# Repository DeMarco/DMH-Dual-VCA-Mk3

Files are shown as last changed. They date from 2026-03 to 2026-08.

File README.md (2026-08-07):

# DMH-Dual-VCA-Mk3
Version 3 of my stereo VCA in Kosmo format, now including voltage controlled panning and optional clipping and distortion!







## Features

- 2 channels, A and B
- 2 CV inputs per channel, each one with its own attenuverter knob
- Unipolar control voltage: 0V means VCA is fully closed (gain = 0), +10V means completely open (gain = 1)
- 1 offset knob per channel, useful to bias bipolar CV signals like those from LFOs
- The offset setting and attenuverted CV inputs of each channel are summed
- Toggle switches to select between pan/balanced/tremolo mode, and clipping/distortion
- Pan mode: output volue of both channels is halved. Pan CV signal will increase one channel's volume and decrease the other's simultaneously.
- Balanced mode: same as Pan mode, but both channels volume are biased with half the Pan CV signal amplitude, which preserves overall volume during panning.
- Tremolo mode: both channels duck in response to Pan CV.
- The Pan knob can be used to manually change panning when no Pan CV is plugged in. It becomes an attenuverter when Pan CV is used.
- Clip mode: 4v7 Zener diode pairs are applied to both channel outputs, effectively limiting output to about +/-5V.
- Distorted mode: 3v0 Zener diode pairs and 2x gain is applied to both channels output, effectively distorting and limiting output to +/-5V.
- LEDs indicate when the output levels pre-clipping/distortion peak above 5V, so you know that Clip mode is clipping the output when engaged.

Demo video: https://www.instagram.com/reel/DbrHDk0sg0o/?utm_source=ig_web_copy_link&igsh=MzRlODBiNWFlZA==

## Schematic and Gerbers

https://github.com/DeMarco/DMH-Dual-VCA-Mk3/blob/main/Schematic.pdf

https://github.com/DeMarco/DMH-Dual-VCA-Mk3/tree/main/Gerbers

https://github.com/DeMarco/DMH-Dual-VCA-Mk3/blob/main/DMH_Output_BoM.csv

Please note the plug-in VCA submodules are part of another Repo. You need to make 4 of these to assemble the complete module:

https://github.com/DeMarco/DMH-Submodules/tree/main/DMH_Submodule_VCA/Gerbers

## Assembly instructions

Use 11mm long pin headers on the Main PCB to ensure connection with the pin sockets on the Controls PCB.
Other than that, nothing special.
I recommend soldering components in order of height: start with resistors and diodes, then move on to IC sockets, capacitors, transistors and connectors.

### Main PCB




### Controls PCB




### VCA Submodule Mk1




## Calibration

### Attenuverters pot center

t.b.w.

### VCAs symmetry

t.b.w

## Current consumption

+12V --> 38mA

-12V --> 38mA

## Dimensions

Height: 20cm

Width: 5cm

Depth: t.b.c.

## Font

For viewing/customizing in KiCad, I recommend downloading and installing the Nulshock font from Typodermic: https://typodermicfonts.com/nulshock/

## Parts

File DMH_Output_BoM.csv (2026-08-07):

Reference | Value | Footprint | Qty | DNP
C1,C2,C6,C7,C8,C9,C10,C11,C12,C13,C14,C15,C16,C17,C18,C19,C24,C25 | 100nF | Capacitor_THT:C_Disc_D4.3mm_W1.9mm_P5.00mm | 18
C3 | 22pF | Capacitor_THT:C_Disc_D3.0mm_W2.0mm_P2.50mm | 1
C4,C5 | 47uF | Capacitor_THT:CP_Radial_D5.0mm_P2.00mm | 2
C20,C21 | 2.2uF | Capacitor_THT:CP_Radial_D4.0mm_P1.50mm | 2
C22,C23 | 22uF | Capacitor_THT:CP_Radial_D4.0mm_P1.50mm | 2
D1,D2 | 1N4148 | Diode_THT:D_DO-35_SOD27_P7.62mm_Horizontal | 2
D3,D4 | SB140 | Diode_THT:D_DO-41_SOD81_P10.16mm_Horizontal | 2
D5,D6 | LED_R | LED_THT:LED_D3.0mm | 2
D7,D8,D9,D10 | ZPD4V7 | Diode_THT:D_DO-35_SOD27_P7.62mm_Horizontal | 4
D11,D12,D13,D14 | ZPD3V0 | Diode_THT:D_DO-35_SOD27_P7.62mm_Horizontal | 4
J1,J2,J3,J4,J5,J6,J7,J8,J9 | TRS_Jack_6.35mm_Sw | SynthStuff:CUI_SJ-63083D | 9
J11,J13 | Conn_01x06 | Connector_PinHeader_2.54mm:PinHeader_1x06_P2.54mm_Vertical | 2
J12,J21 | Conn_01x08 | Connector_PinHeader_2.54mm:PinHeader_1x08_P2.54mm_Vertical | 2
J14,J16 | Conn_01x06 | Connector_PinSocket_2.54mm:PinSocket_1x06_P2.54mm_Vertical | 2
J15,J24 | Conn_01x08 | Connector_PinSocket_2.54mm:PinSocket_1x08_P2.54mm_Vertical | 2
J18,J19,J22,J23 | Conn_02x03_Odd_Even | Connector_PinSocket_2.54mm:PinSocket_2x03_P2.54mm_Vertical | 4
J25,J26,J27,J28 | Conn_02x03_Odd_Even | Connector_PinHeader_2.54mm:PinHeader_2x03_P2.54mm_Horizontal | 4
J100 | IDC_02x05 | SynthStuff:IDC-Header_2x05_P2.54mm_Vertical_Eurorack | 1
J200 | IDC_02x05 | SynthStuff:IDC-Header_2x05_P2.54mm_Vertical_BackBone | 1
JP1,JP2,JP3,JP4 | Jumper | Connector_PinHeader_2.54mm:PinHeader_1x03_P2.54mm_Vertical | 4
Q1,Q2,Q3,Q4,Q5,Q6,Q7,Q8,Q9,Q10,Q11,Q12 | BC548 | Package_TO_SOT_THT:TO-92L_Inline_Wide | 12
R1,R2 | 3k3 | Resistor_THT:R_Axial_DIN0207_L6.3mm_D2.5mm_P7.62mm_Horizontal | 2
R3,R64,R65,R70,R71 | 33k | Resistor_THT:R_Axial_DIN0207_L6.3mm_D2.5mm_P7.62mm_Horizontal | 5
R4,R5,R6,R7,R8,R12,R13,R14,R15,R16,R17,R25,R26,R27,R28,R29,R37,R38,R39,R40,R41,R49,R50,R51,R52,R53,R61,R62,R63,R67,R68,R69,R73,R74,R75,R80,R81,R82,R83,R84,R87,R92,R93,R96,R97 | 100k | Resistor_THT:R_Axial_DIN0207_L6.3mm_D2.5mm_P7.62mm_Horizontal | 45
R9,R11,R19,R21,R31,R33,R43,R45,R55,R57 | 20k | Resistor_THT:R_Axial_DIN0207_L6.3mm_D2.5mm_P7.62mm_Horizontal | 10
R10,R20,R23,R24,R32,R35,R36,R44,R47,R48,R56,R59,R60,R76,R78 | 10k | Resistor_THT:R_Axial_DIN0207_L6.3mm_D2.5mm_P7.62mm_Horizontal | 15
R18,R22,R30,R34,R42,R46,R54,R58 | 100R | Resistor_THT:R_Axial_DIN0207_L6.3mm_D2.5mm_P7.62mm_Horizontal | 8
R66,R72 | 18k | Resistor_THT:R_Axial_DIN0207_L6.3mm_D2.5mm_P7.62mm_Horizontal | 2
R77,R79 | 1k5 | Resistor_THT:R_Axial_DIN0207_L6.3mm_D2.5mm_P7.62mm_Horizontal | 2
R85,R88 | 4k7 | Resistor_THT:R_Axial_DIN0207_L6.3mm_D2.5mm_P7.62mm_Horizontal | 2
R86,R89,R100,R101 | 1k | Resistor_THT:R_Axial_DIN0207_L6.3mm_D2.5mm_P7.62mm_Horizontal | 4
R90,R91,R98,R99 | 2k2 | Resistor_THT:R_Axial_DIN0207_L6.3mm_D2.5mm_P7.62mm_Horizontal | 4
R94,R95 | 220k | Resistor_THT:R_Axial_DIN0207_L6.3mm_D2.5mm_P7.62mm_Horizontal | 2
RV1 | 50k | Potentiometer_THT:Potentiometer_Bourns_3296W_Vertical | 1
RV2,RV3,RV4,RV5 | 100k | Potentiometer_THT:Potentiometer_Bourns_3296X_Horizontal | 4
RV6 | 50k | Potentiometer_THT:Potentiometer_Alps_RK09L_Double_Vertical | 1
RV7,RV8,RV12,RV13 | 100k | SynthStuff:Potentiometer_TT_P110KH1 | 4
RV9,RV10,RV14,RV15 | 50k | Potentiometer_THT:Potentiometer_Bourns_3296X_Horizontal | 4
RV11,RV16 | 100k | SynthStuff:Potentiometer_Alpha_RD901F-40-00D_Single_Vertical | 2
SW1 | SW_DPDT_3way | SynthStuff:Toggle_Switch_2_Poles_TE | 1
SW2 | SW_DPDT_OnOffOn_x2 | SynthStuff:Toggle_Switch_2_Poles_TE | 1
U1,U2 | LM4040LP-5 | Package_TO_SOT_THT:TO-92L_Inline_Wide | 2
U3,U9,U10 | TL074 | Package_DIP:DIP-14_W7.62mm_Socket | 3
U4,U5,U6,U7,U8 | TL072 | Package_DIP:DIP-8_W7.62mm_Socket | 5

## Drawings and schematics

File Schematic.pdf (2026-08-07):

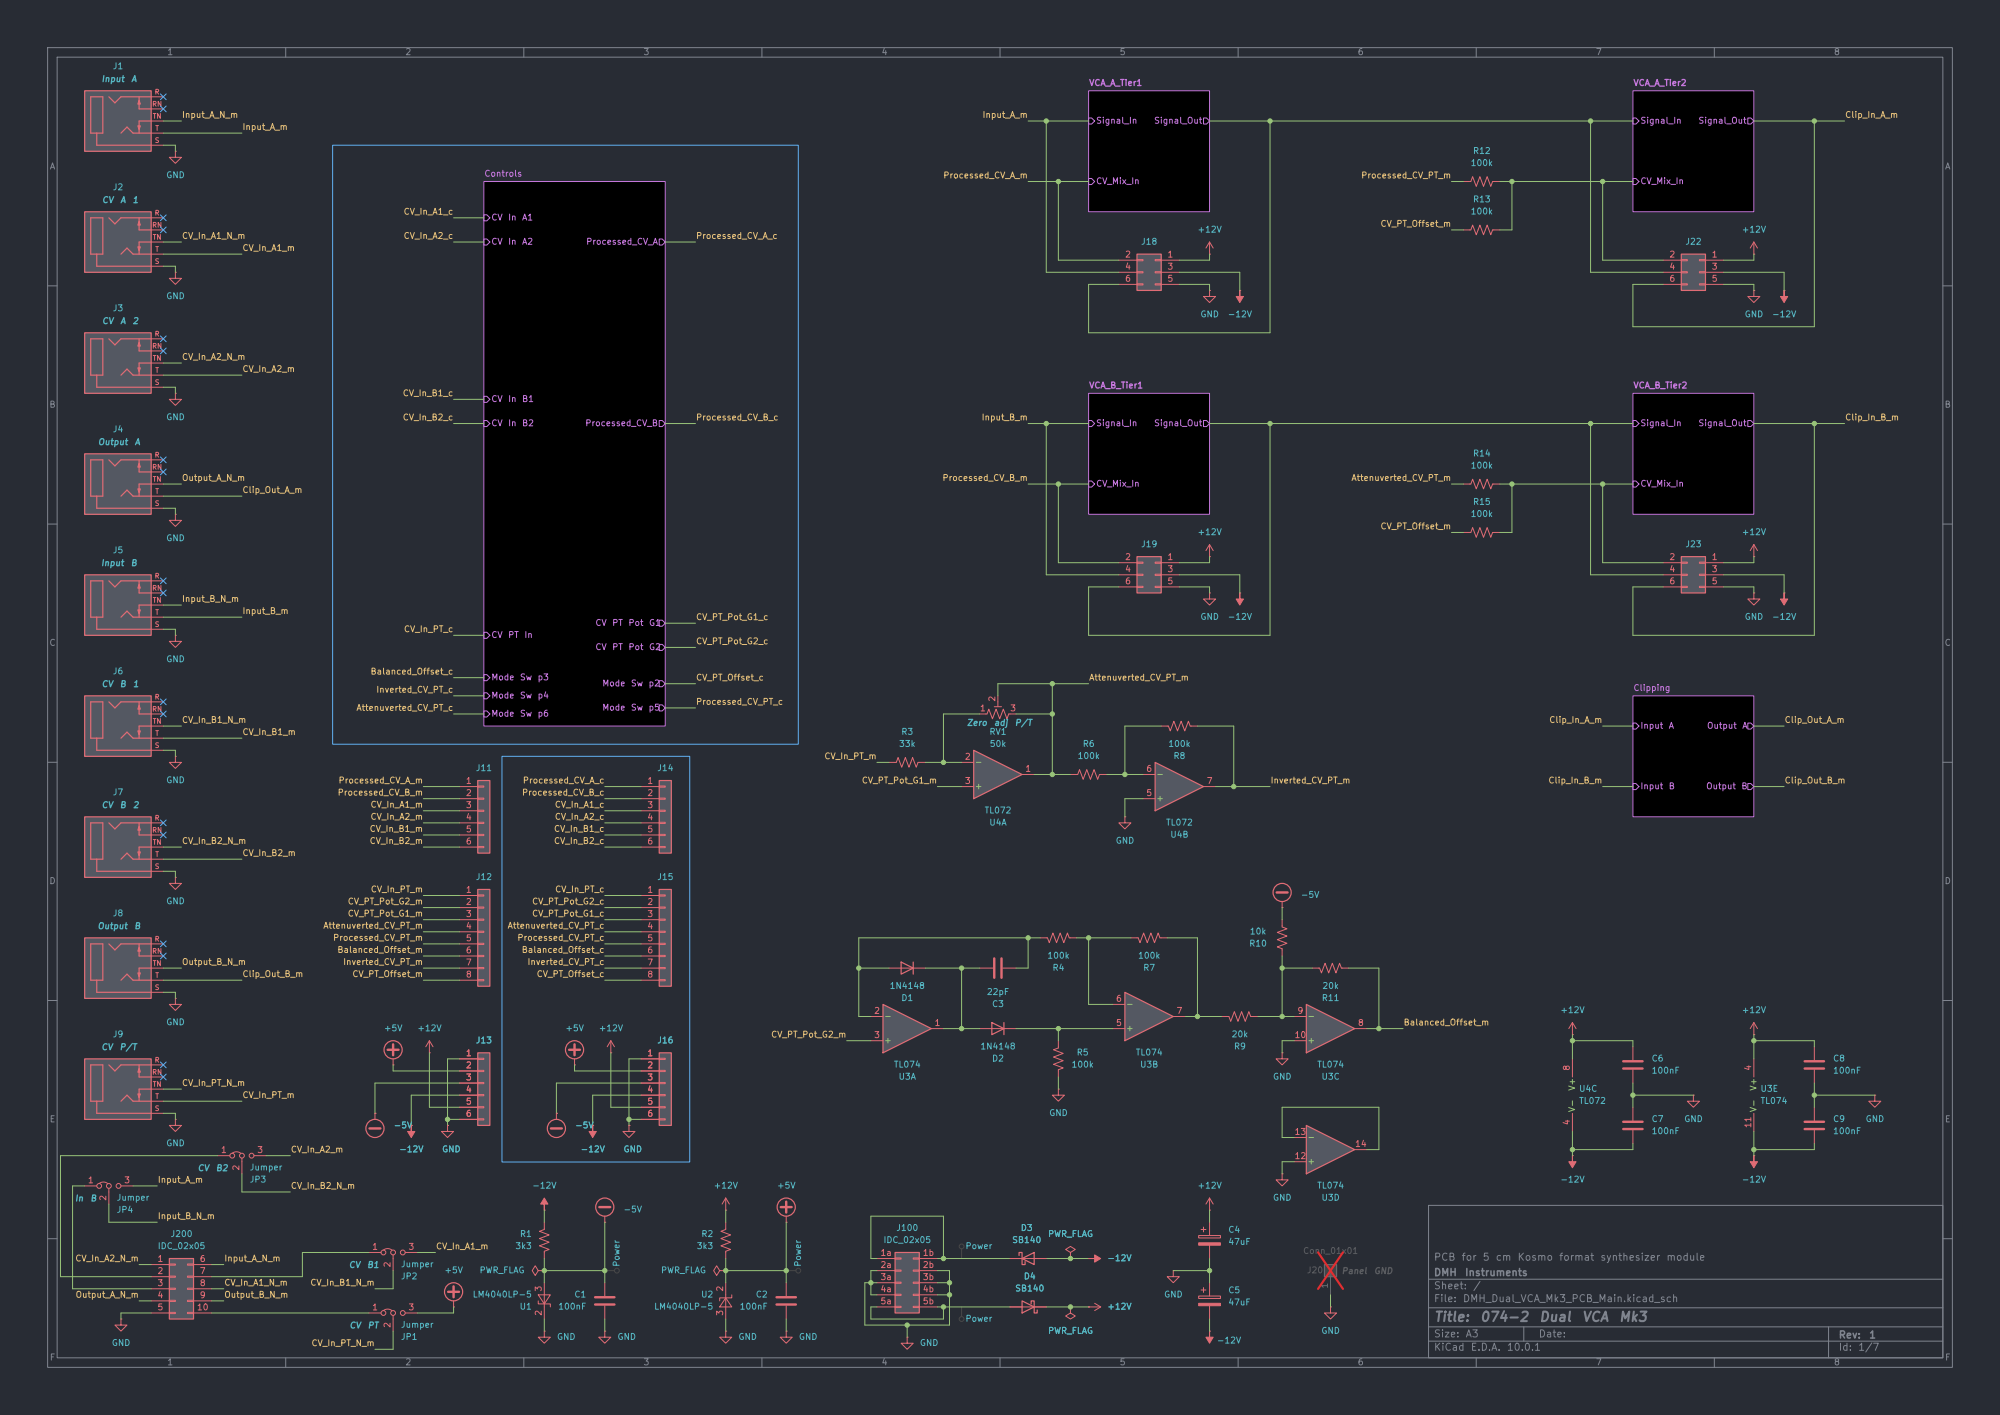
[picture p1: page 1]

PCB for 5 cm Kosmo format synthesizer module
DMH Instruments
Sheet: /
File: DMH_Dual_VCA_Mk3_PCB_Main.kicad_sch
Title: 074-2 Dual VCA Mk3

Size: A3 | Rev: 1 | F Date:
KiCad E.D.A. 10.0.1 | Id: 1/7

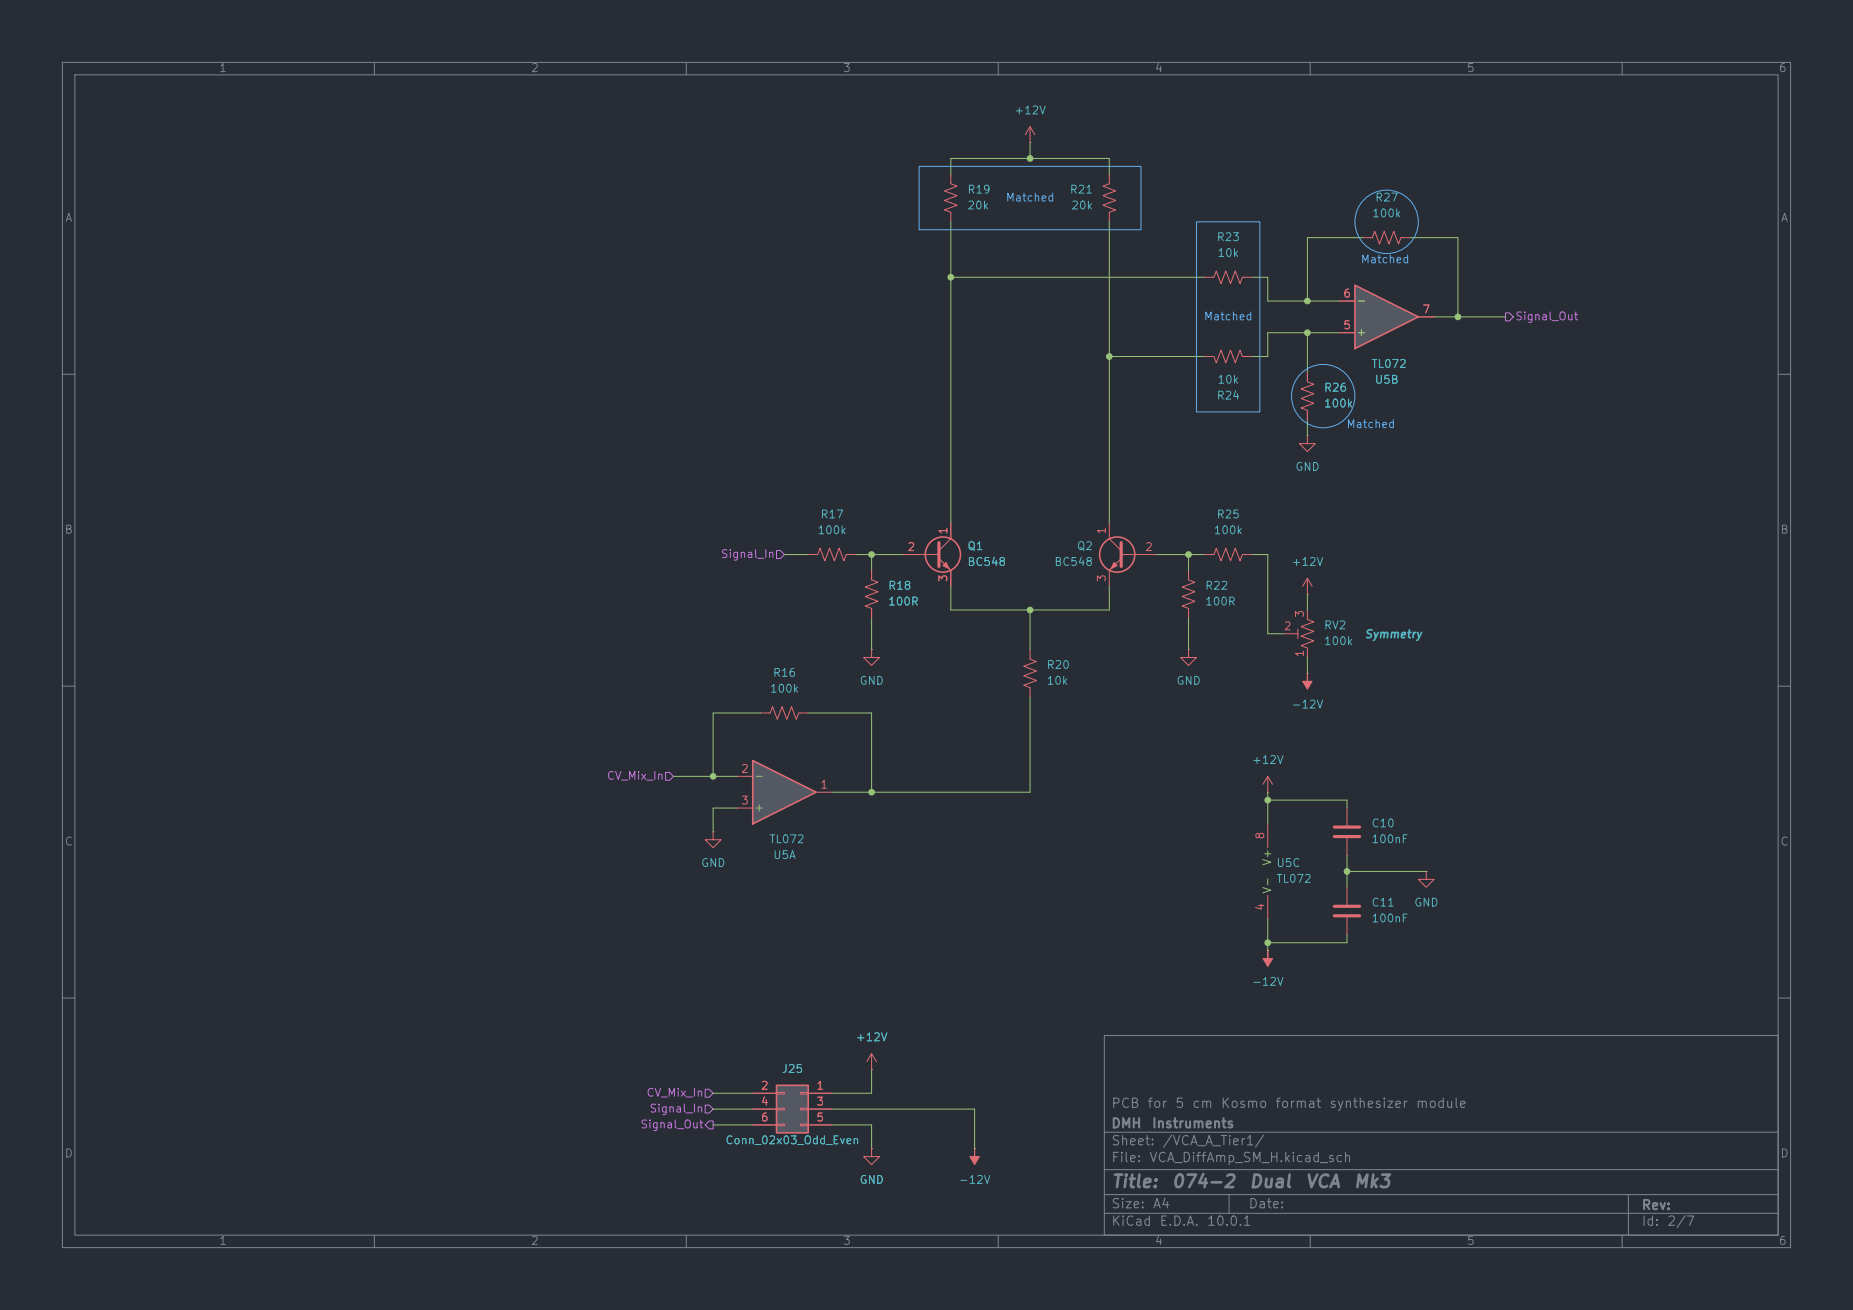
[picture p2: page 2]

PCB for 5 cm Kosmo format synthesizer module
DMH Instruments
Sheet: /VCA_A_Tier1/
File: VCA_DiffAmp_SM_H.kicad_sch
Title: 074-2 Dual VCA Mk3

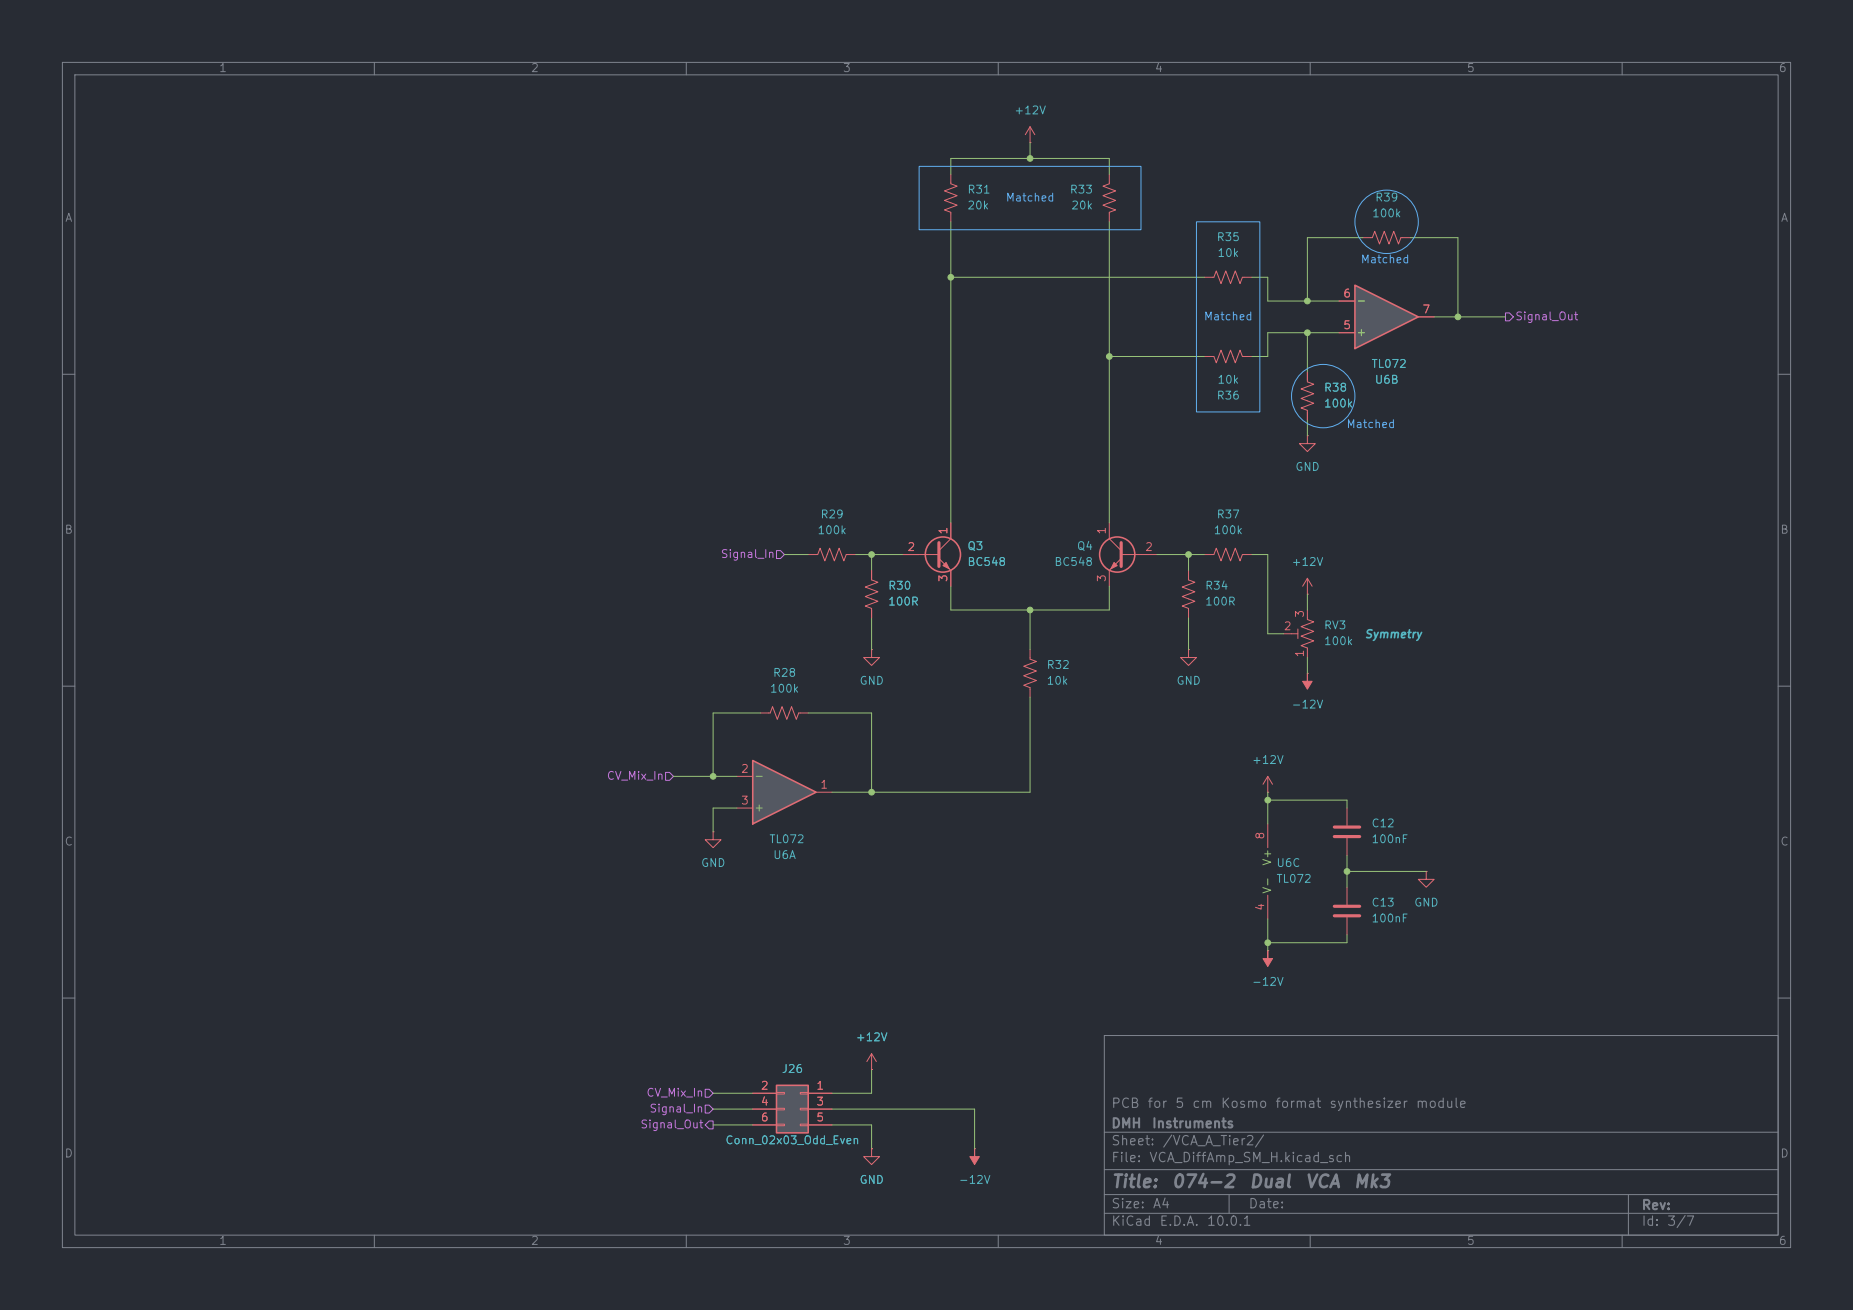
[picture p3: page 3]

PCB for 5 cm Kosmo format synthesizer module
DMH Instruments
Sheet: /VCA_A_Tier2/
File: VCA_DiffAmp_SM_H.kicad_sch
Title: 074-2 Dual VCA Mk3

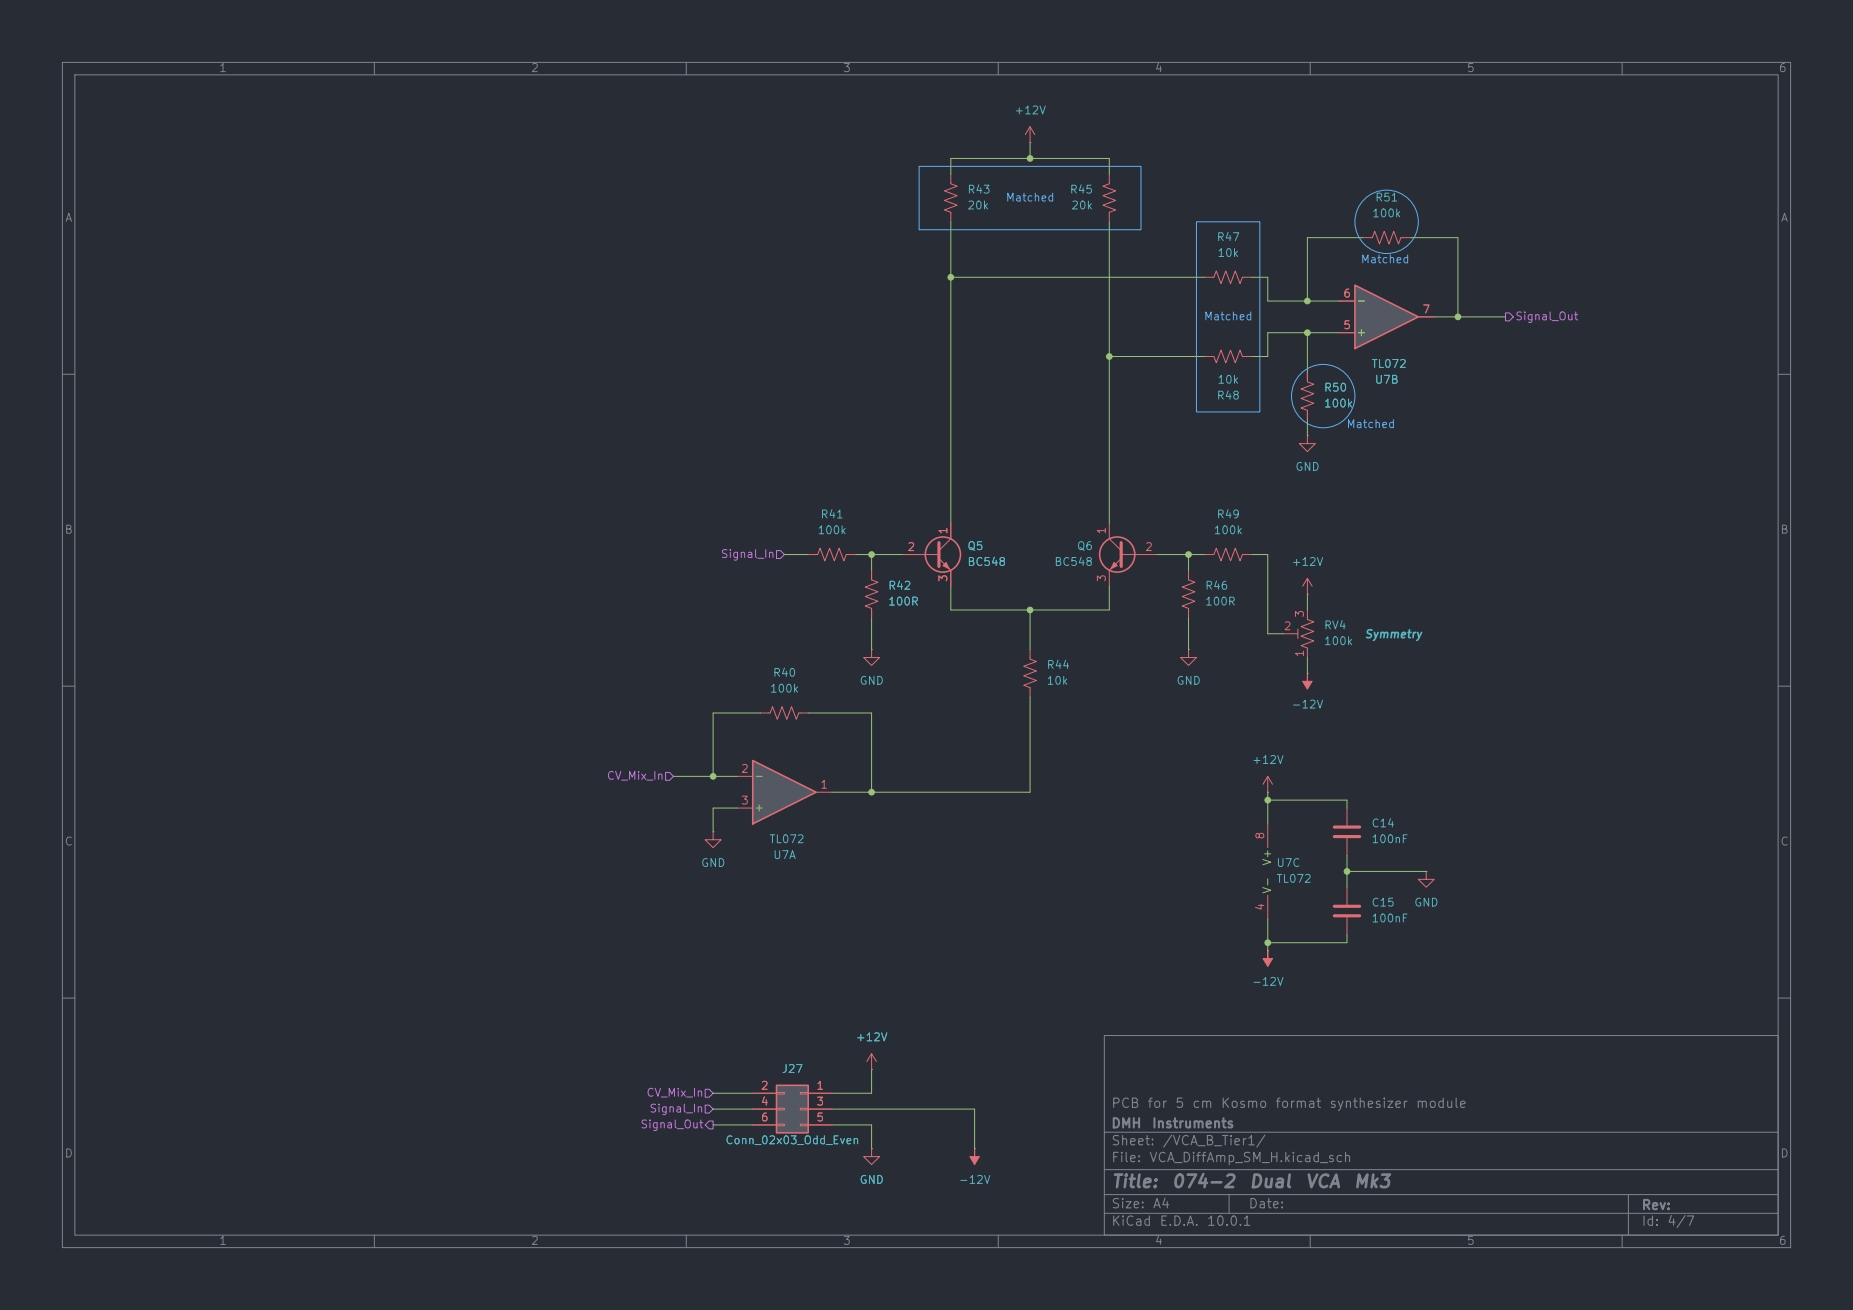
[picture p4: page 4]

PCB for 5 cm Kosmo format synthesizer module
DMH Instruments
Sheet: /VCA_B_Tier1/
File: VCA_DiffAmp_SM_H.kicad_sch
Title: 074-2 Dual VCA Mk3

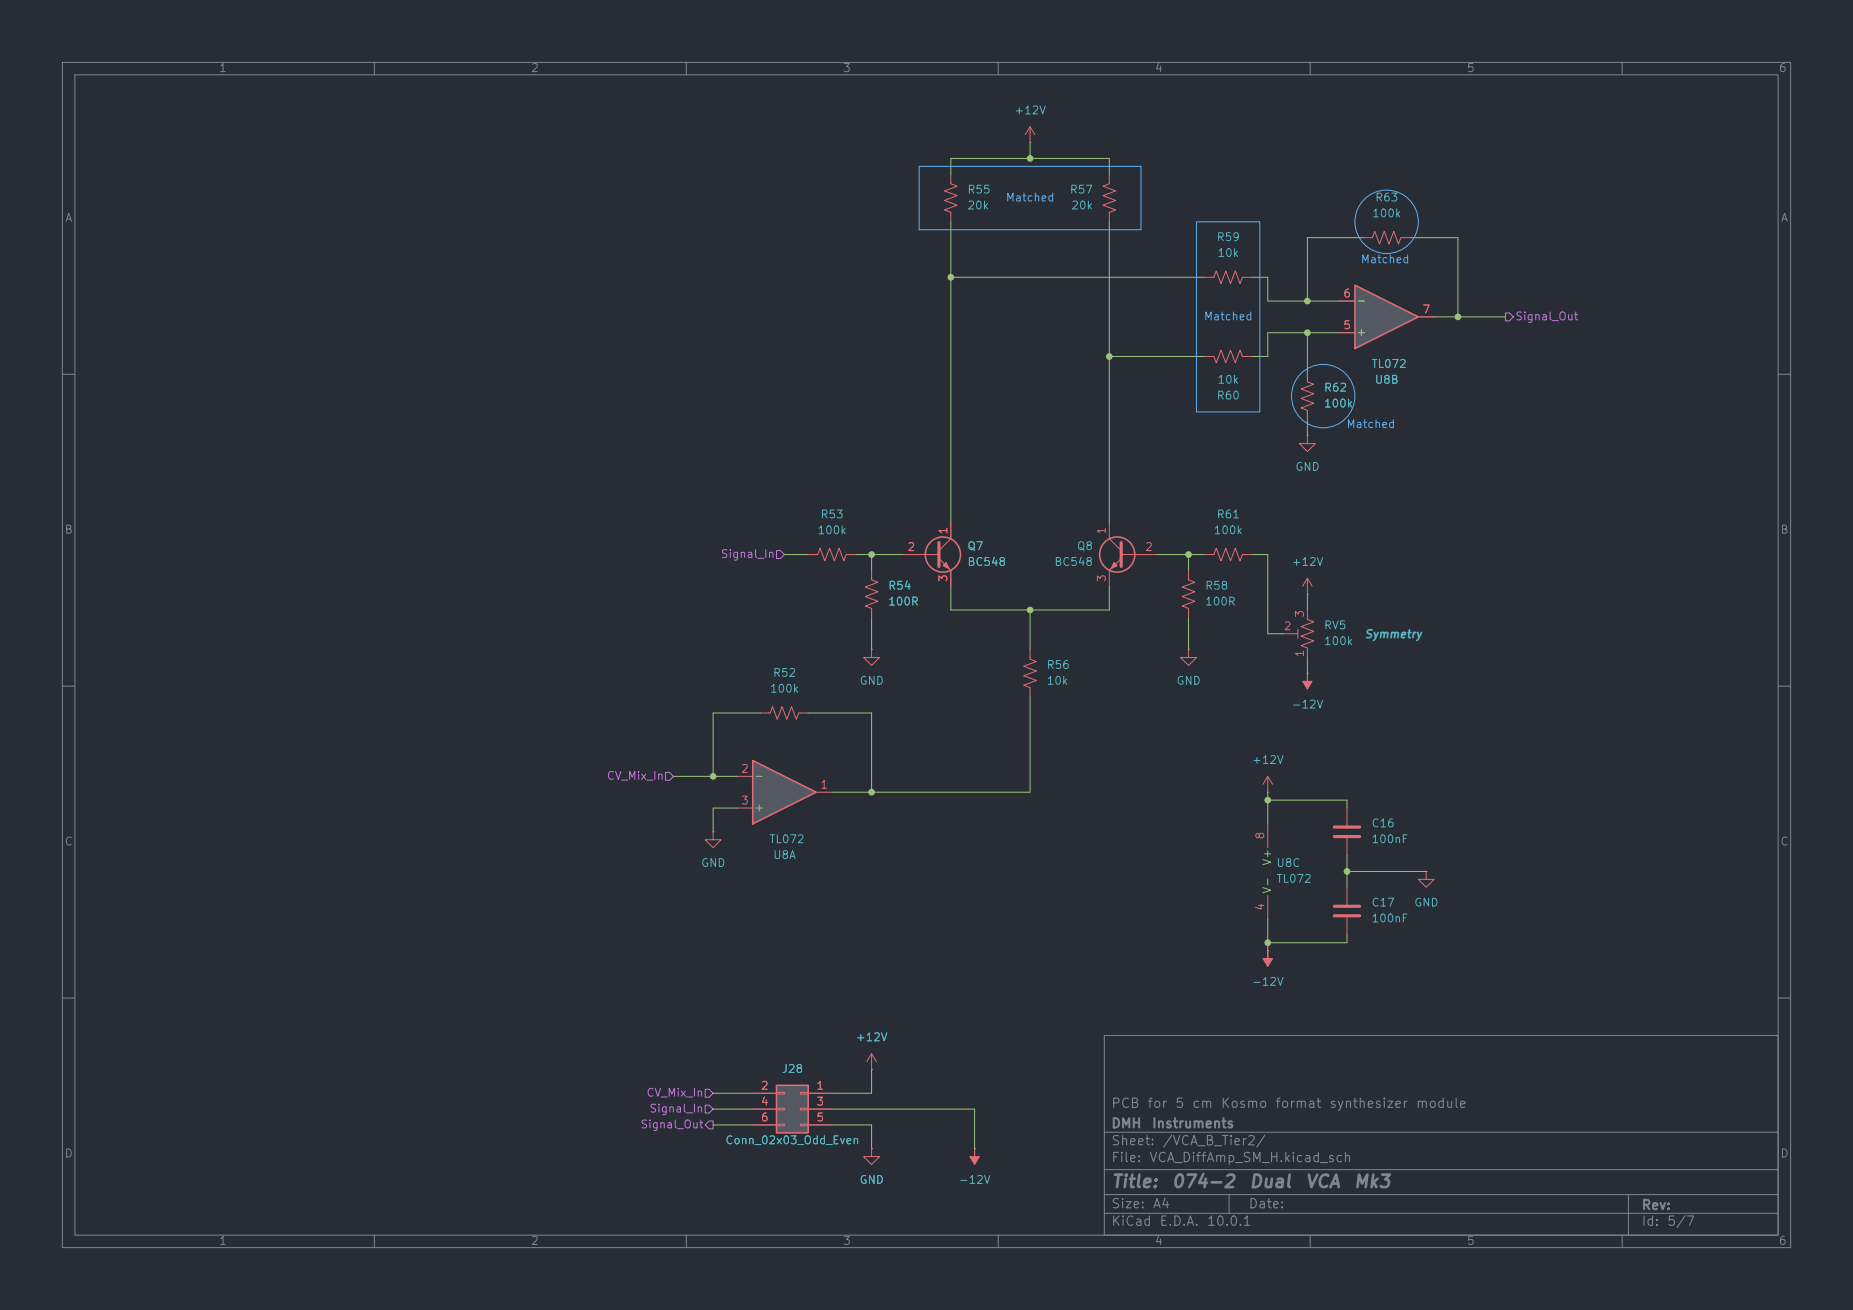
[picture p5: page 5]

PCB for 5 cm Kosmo format synthesizer module
DMH Instruments
Sheet: /VCA_B_Tier2/
File: VCA_DiffAmp_SM_H.kicad_sch
Title: 074-2 Dual VCA Mk3

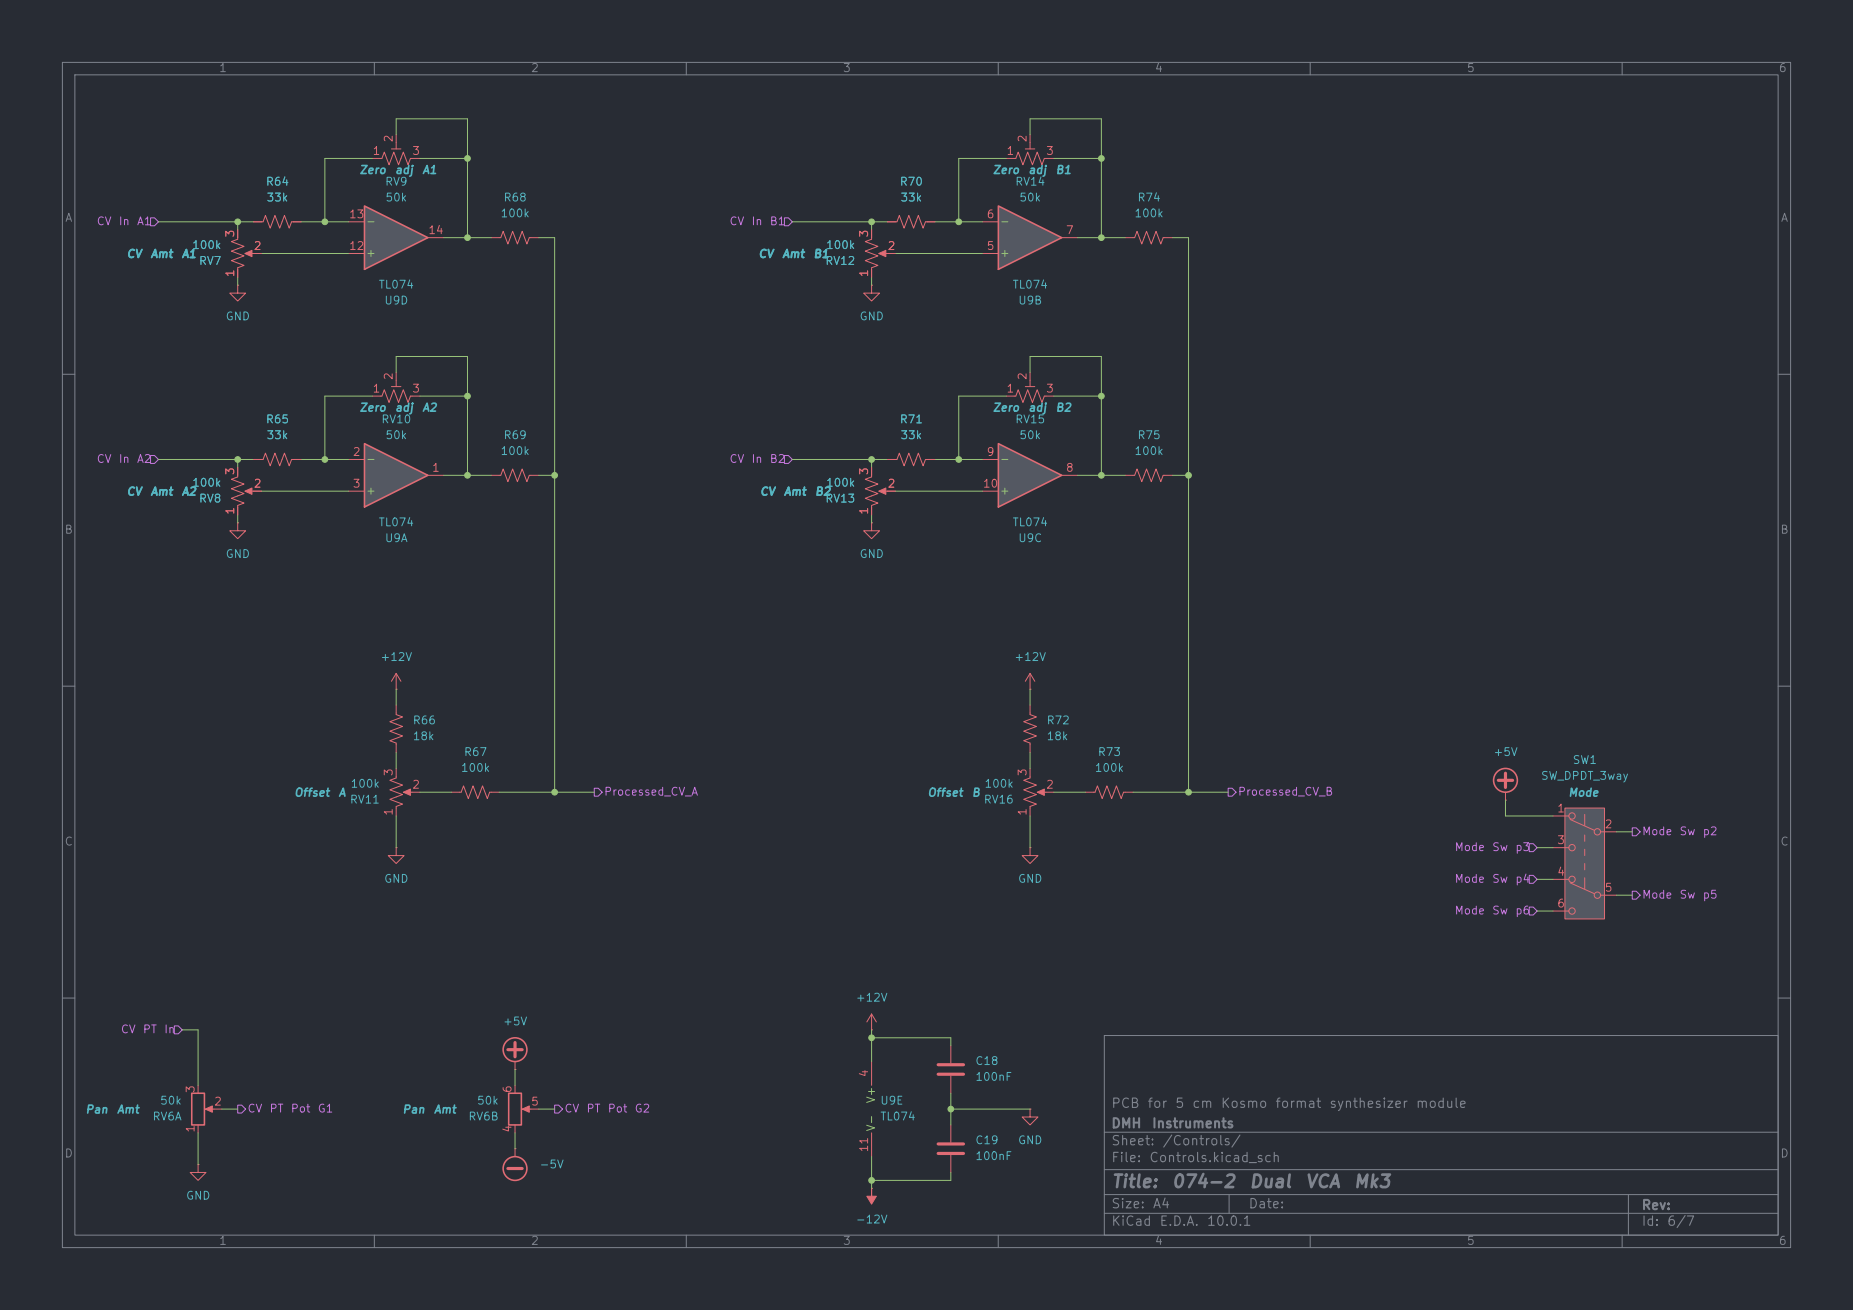
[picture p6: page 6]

PCB for 5 cm Kosmo format synthesizer module
DMH Instruments
Sheet: /Controls/
File: Controls.kicad_sch
Title: 074-2 Dual VCA Mk3

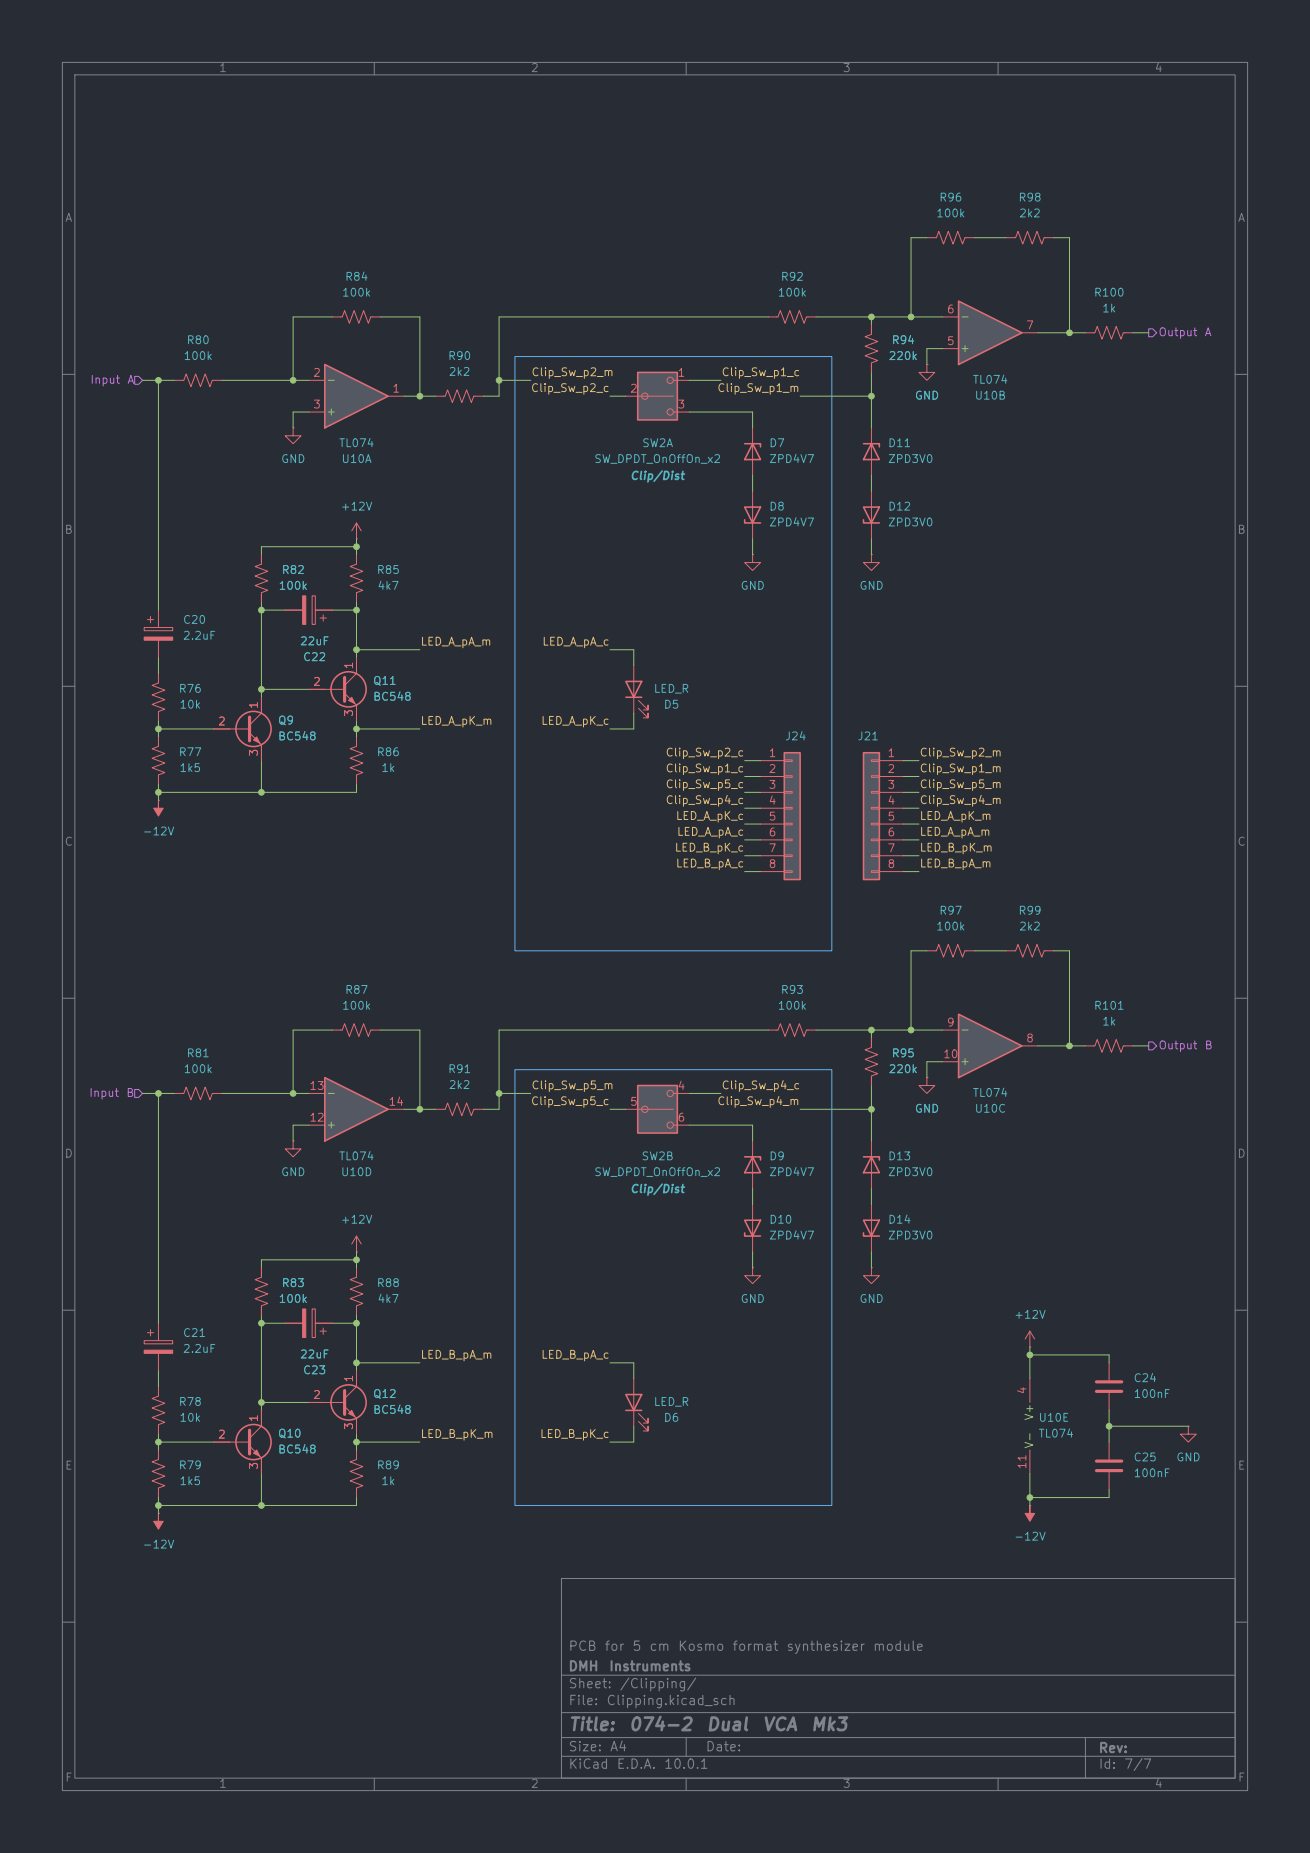
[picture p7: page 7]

PCB for 5 cm Kosmo format synthesizer module
DMH Instruments
Sheet: /Clipping/
File: Clipping.kicad_sch
Title: 074-2 Dual VCA Mk3

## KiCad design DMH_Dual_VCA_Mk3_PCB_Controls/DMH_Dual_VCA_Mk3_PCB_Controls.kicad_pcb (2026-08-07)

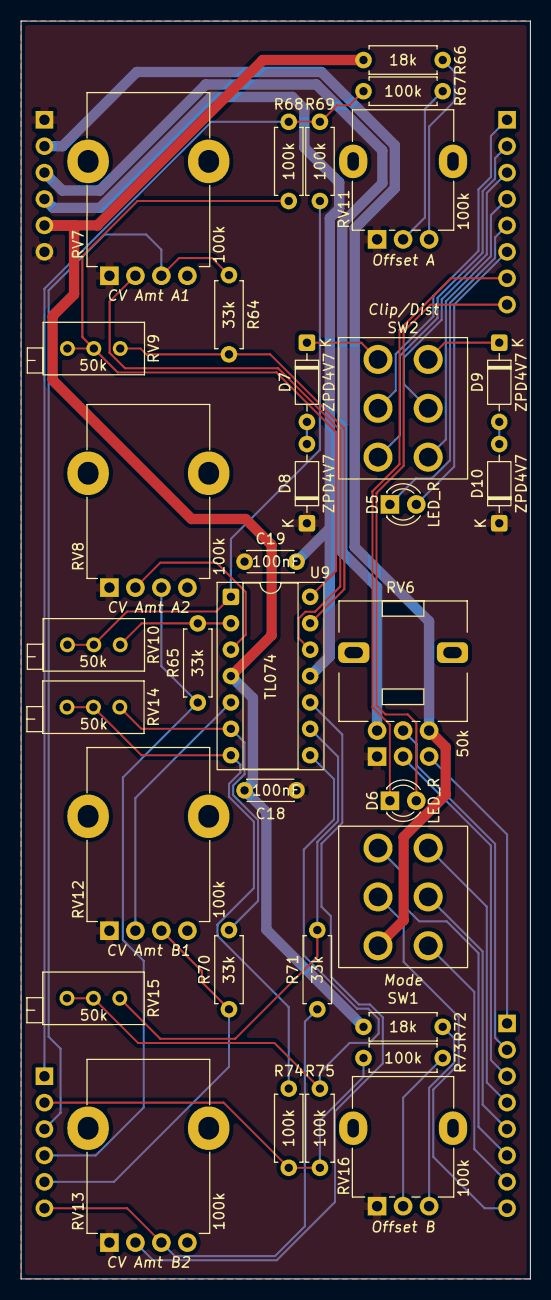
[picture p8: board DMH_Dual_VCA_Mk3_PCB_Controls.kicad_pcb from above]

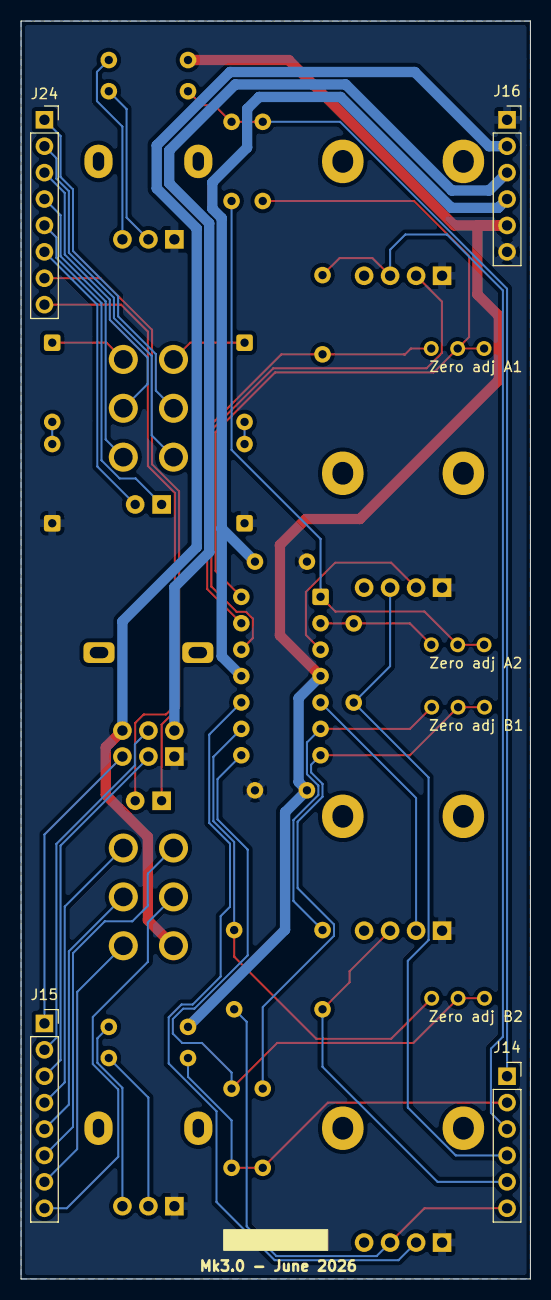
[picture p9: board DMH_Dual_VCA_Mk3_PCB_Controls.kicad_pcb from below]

Board: 2 copper layers, 49.0 x 121.0 mm, 38 parts (4 on the bottom side), 47 nets.

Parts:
C18, C19: 100nF; C_Disc_D4.3mm_W1.9mm_P5.00mm
D5, D6: LED_R; LED_D3.0mm
D7, D8, D9, D10: ZPD4V7; D_DO-35_SOD27_P7.62mm_Horizontal
J14, J16: Conn_01x06; PinSocket_1x06_P2.54mm_Vertical
J15, J24: Conn_01x08; PinSocket_1x08_P2.54mm_Vertical
R64, R65, R70, R71: 33k; R_Axial_DIN0207_L6.3mm_D2.5mm_P7.62mm_Horizontal
R66, R72: 18k; R_Axial_DIN0207_L6.3mm_D2.5mm_P7.62mm_Horizontal
R67, R68, R69, R73, R74, R75: 100k; R_Axial_DIN0207_L6.3mm_D2.5mm_P7.62mm_Horizontal
RV6: 50k; Potentiometer_Alps_RK09L_Double_Vertical
RV7, RV8, RV12, RV13: 100k; Potentiometer_TT_P110KH1
RV9, RV10, RV14, RV15: 50k; Potentiometer_Bourns_3296X_Horizontal
RV11, RV16: 100k; Potentiometer_Alpha_RD901F-40-00D_Single_Vertical
SW1: SW_DPDT_3way; Toggle_Switch_2_Poles_TE
SW2: SW_DPDT_OnOffOn_x2; Toggle_Switch_2_Poles_TE
U9: TL074; DIP-14_W7.62mm_Socket

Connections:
+5V: J16.2, RV6.6, SW1.1 (A)
+12V: C18.1, J16.5, R66.2, R72.2, U9.4 (V+)
-5V: J16.3, RV6.4
-12V: C19.2, J16.4, U9.11 (V-)
/Attenuverted_CV_PT_c: J15.4, SW1.6 (C)
/Balanced_Offset_c: J15.6, SW1.3 (C)
/CV_In_A1_c: J14.3, R64.1, RV7.3
/CV_In_A2_c: J14.4, R65.1, RV8.3
/CV_In_B1_c: J14.5, R70.1, RV12.3
/CV_In_B2_c: J14.6, R71.1, RV13.3
/CV_In_PT_c: J15.1, RV6.3
/CV_PT_Offset_c: J15.8, SW1.2 (B)
/CV_PT_Pot_G1_c: J15.3, RV6.2
/CV_PT_Pot_G2_c: J15.2, RV6.5
/Clipping/Clip_Sw_p1_c: J24.2, SW2.1 (A)
/Clipping/Clip_Sw_p2_c: J24.1, SW2.2 (B)
/Clipping/Clip_Sw_p4_c: J24.4, SW2.4 (A)
/Clipping/Clip_Sw_p5_c: J24.3, SW2.5 (B)
/Clipping/LED_A_pA_c: D5.2 (A), J24.6
/Clipping/LED_A_pK_c: D5.1 (K), J24.5
/Clipping/LED_B_pA_c: D6.2 (A), J24.8
/Clipping/LED_B_pK_c: D6.1 (K), J24.7
/Inverted_CV_PT_c: J15.7, SW1.4 (A)
/Processed_CV_A_c: J14.1, R67.2, R68.2, R69.2
/Processed_CV_B_c: J14.2, R73.2, R74.2, R75.2
/Processed_CV_PT_c: J15.5, SW1.5 (B)
GND: C18.2, C19.1, D8.1 (K), D10.1 (K), J16.1, J16.6, RV6.1, RV7.1, RV8.1, RV11.1, RV12.1, RV13.1, RV16.1
unnamed: D7.2 (A), D8.2 (A)
unnamed: D7.1 (K), SW2.3 (C)
unnamed: D9.1 (K), SW2.6 (C)
unnamed: D9.2 (A), D10.2 (A)
unnamed: R66.1, RV11.3
unnamed: R67.1, RV11.2
unnamed: R68.1, RV9.2, RV9.3, U9.14
unnamed: R69.1, RV10.2, RV10.3, U9.1
unnamed: R72.1, RV16.3
unnamed: R73.1, RV16.2
unnamed: R74.1, RV14.2, RV14.3, U9.7
unnamed: R75.1, RV15.2, RV15.3, U9.8
unnamed: RV8.2, U9.3 (+)
unnamed: R65.2, RV10.1, U9.2 (-)
unnamed: RV12.2, U9.5 (+)
unnamed: R70.2, RV14.1, U9.6 (-)
unnamed: RV13.2, U9.10 (+)
unnamed: R71.2, RV15.1, U9.9 (-)
unnamed: RV7.2, U9.12 (+)
unnamed: R64.2, RV9.1, U9.13 (-)

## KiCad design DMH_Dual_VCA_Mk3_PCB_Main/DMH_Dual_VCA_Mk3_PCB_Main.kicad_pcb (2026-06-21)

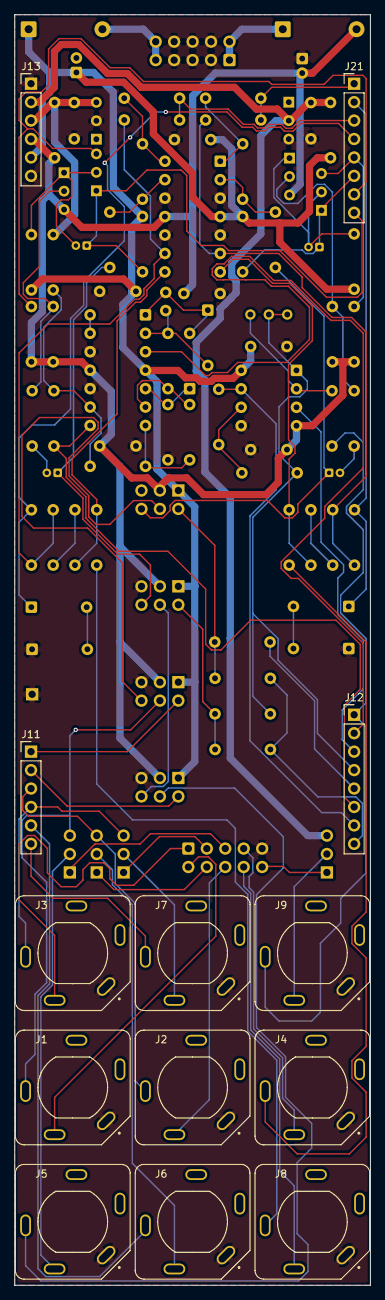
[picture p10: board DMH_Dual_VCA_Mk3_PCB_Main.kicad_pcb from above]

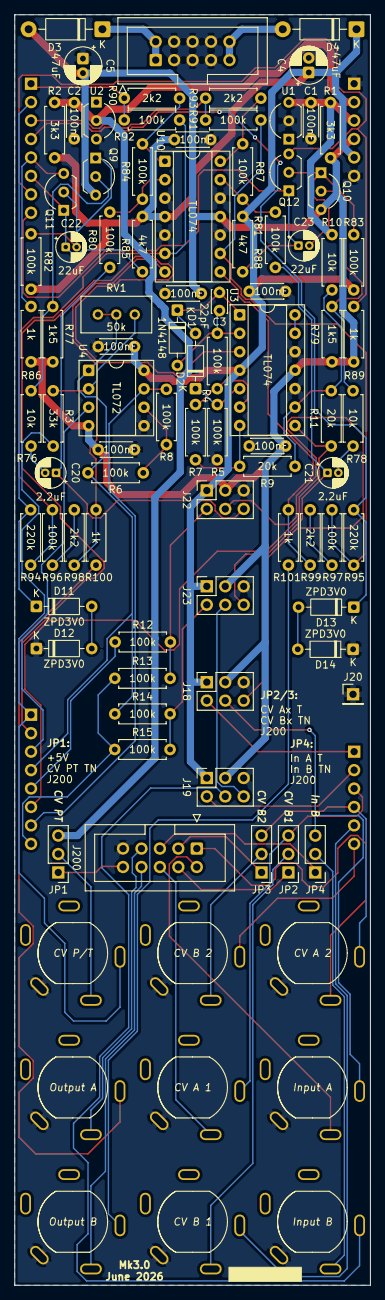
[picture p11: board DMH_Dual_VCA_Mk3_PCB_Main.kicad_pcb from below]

Board: 2 copper layers, 49.0 x 175.0 mm, 98 parts (85 on the bottom side), 79 nets.

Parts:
C1, C2, C6, C7, C8, C9, C24, C25: 100nF; C_Disc_D4.3mm_W1.9mm_P5.00mm
C3: 22pF; C_Disc_D3.0mm_W2.0mm_P2.50mm
C4, C5: 47uF; CP_Radial_D5.0mm_P2.00mm
C20, C21: 2.2uF; CP_Radial_D4.0mm_P1.50mm
C22, C23: 22uF; CP_Radial_D4.0mm_P1.50mm
D1, D2: 1N4148; D_DO-35_SOD27_P7.62mm_Horizontal
D3, D4: SB140; D_DO-41_SOD81_P10.16mm_Horizontal
D11, D12, D13, D14: ZPD3V0; D_DO-35_SOD27_P7.62mm_Horizontal
J1, J2, J3, J4, J5, J6, J7, J8, J9: TRS_Jack_6.35mm_Sw; CUI_SJ-63083D
J11, J13: Conn_01x06; PinHeader_1x06_P2.54mm_Vertical
J12, J21: Conn_01x08; PinHeader_1x08_P2.54mm_Vertical
J18, J19, J22, J23: Conn_02x03_Odd_Even; PinSocket_2x03_P2.54mm_Vertical
J20: Conn_01x01; PinHeader_1x01_P2.54mm_Vertical
J100: IDC_02x05; IDC-Header_2x05_P2.54mm_Vertical_Eurorack
J200: IDC_02x05; IDC-Header_2x05_P2.54mm_Vertical_BackBone
JP1, JP2, JP3, JP4: Jumper; PinHeader_1x03_P2.54mm_Vertical
Q9, Q10, Q11, Q12: BC548; TO-92L_Inline_Wide
R1, R2: 3k3; R_Axial_DIN0207_L6.3mm_D2.5mm_P7.62mm_Horizontal
R3: 33k; R_Axial_DIN0207_L6.3mm_D2.5mm_P7.62mm_Horizontal
R4, R5, R6, R7, R8, R12, R13, R14, R15, R80, R81, R82, R83, R84, R87, R92, R93, R96, R97: 100k; R_Axial_DIN0207_L6.3mm_D2.5mm_P7.62mm_Horizontal
R9, R11: 20k; R_Axial_DIN0207_L6.3mm_D2.5mm_P7.62mm_Horizontal
R10, R76, R78: 10k; R_Axial_DIN0207_L6.3mm_D2.5mm_P7.62mm_Horizontal
R77, R79: 1k5; R_Axial_DIN0207_L6.3mm_D2.5mm_P7.62mm_Horizontal
R85, R88: 4k7; R_Axial_DIN0207_L6.3mm_D2.5mm_P7.62mm_Horizontal
R86, R89, R100, R101: 1k; R_Axial_DIN0207_L6.3mm_D2.5mm_P7.62mm_Horizontal
R90, R91, R98, R99: 2k2; R_Axial_DIN0207_L6.3mm_D2.5mm_P7.62mm_Horizontal
R94, R95: 220k; R_Axial_DIN0207_L6.3mm_D2.5mm_P7.62mm_Horizontal
RV1: 50k; Potentiometer_Bourns_3296W_Vertical
U1, U2: LM4040LP-5; TO-92L_Inline_Wide
U3, U10: TL074; DIP-14_W7.62mm_Socket
U4: TL072; DIP-8_W7.62mm_Socket

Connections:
+5V: C2.1, J13.2, JP1.3 (B), R2.1, U2.2 (K)
+12V: C4.1, C6.1, C8.1, C24.1, D4.1 (K), J13.5, J18.1, J19.1, J22.1, J23.1, R2.2, R82.2, R83.2, R85.2, R88.2, U3.4 (V+), U4.8 (V+), U10.4 (V+)
-5V: C1.1, J13.3, R1.1, R10.1, U1.3 (A)
-12V: C5.2, C7.2, C9.2, C25.2, D3.2 (A), J13.4, J18.3, J19.3, J22.3, J23.3, Q9.3 (E), Q10.3 (E), R1.2, R77.1, R79.1, R86.1, R89.1, U3.11 (V-), U4.4 (V-), U10.11 (V-)
/Attenuverted_CV_PT_m: J12.4, R6.1, R14.1, RV1.2, RV1.3, U4.1
/Balanced_Offset_m: J12.6, R11.1, U3.8
/CV_In_A1_N_m: J2.TN (2), J200.8
/CV_In_A1_m: J2.T (3), J11.3, JP2.3 (B)
/CV_In_A2_N_m: J3.TN (2), J200.1
/CV_In_A2_m: J3.T (3), J11.4, JP3.3 (B)
/CV_In_B1_N_m: J6.TN (2), JP2.2 (C)
/CV_In_B1_m: J6.T (3), J11.5
/CV_In_B2_N_m: J7.TN (2), JP3.2 (C)
/CV_In_B2_m: J7.T (3), J11.6
/CV_In_PT_N_m: J9.TN (2), JP1.2 (C)
/CV_In_PT_m: J9.T (3), J12.1, R3.1
/CV_PT_Offset_m: J12.8, R13.1, R15.1
/CV_PT_Pot_G1_m: J12.3, U4.3 (+)
/CV_PT_Pot_G2_m: J12.2, U3.3 (+)
/Clip_In_A_m: C20.1, J22.6, R80.1
/Clip_In_B_m: C21.1, J23.6, R81.1
/Clip_Out_A_m: J4.T (3), R100.2
/Clip_Out_B_m: J8.T (3), R101.2
/Clipping/Clip_Sw_p1_m: D11.1 (K), J21.2, R94.1
/Clipping/Clip_Sw_p2_m: J21.1, R90.2, R92.1
/Clipping/Clip_Sw_p4_m: D13.1 (K), J21.4, R95.1
/Clipping/Clip_Sw_p5_m: J21.3, R91.2, R93.1
/Clipping/LED_A_pA_m: C22.1, J21.6, Q11.1 (C), R85.1
/Clipping/LED_A_pK_m: J21.5, Q11.3 (E), R86.2
/Clipping/LED_B_pA_m: C23.1, J21.8, Q12.1 (C), R88.1
/Clipping/LED_B_pK_m: J21.7, Q12.3 (E), R89.2
/Input_A_N_m: J1.TN (2), J200.6
/Input_A_m: J1.T (3), J18.4, JP4.3 (B)
/Input_B_N_m: J5.TN (2), JP4.2 (C)
/Input_B_m: J5.T (3), J19.4
/Inverted_CV_PT_m: J12.7, R8.2, U4.7
/Output_A_N_m: J4.TN (2), J200.4
/Output_B_N_m: J8.TN (2), J200.9
/Processed_CV_A_m: J11.1, J18.2
/Processed_CV_B_m: J11.2, J19.2
/Processed_CV_PT_m: J12.5, R12.1
/VCA_A_Tier1/Signal_Out: J18.6, J22.4
/VCA_A_Tier2/CV_Mix_In: J22.2, R12.2, R13.2
/VCA_B_Tier1/Signal_Out: J19.6, J23.4
/VCA_B_Tier2/CV_Mix_In: J23.2, R14.2, R15.2
GND: C1.2, C2.2, C4.2, C5.1, C6.2, C7.1, C8.2, C9.1, C24.2, C25.1, D12.1 (K), D14.1 (K), J1.S (1), J2.S (1), J3.S (1), J4.S (1), J5.S (1), J6.S (1), J7.S (1), J8.S (1), J9.S (1), J13.1, J13.6, J18.5, J19.5, J20.1 (Pin_1_1), J22.5, J23.5, J100.2a, J100.2b, J100.3a, J100.3b, J100.4a, J100.4b, J200.5, R5.2, U1.2 (K), U2.3 (A), U3.10 (+), U3.12 (+), U4.5 (+), U10.3 (+), U10.5 (+), U10.10 (+), U10.12 (+)
unnamed: C20.2, R76.2
unnamed: C21.2, R78.2
unnamed: C3.2, D1.2 (A), R4.2, U3.2 (-)
unnamed: C3.1, D1.1 (K), D2.2 (A), U3.1
unnamed: D2.1 (K), R5.1, U3.5 (+)
unnamed: D3.1 (K), J100.1a, J100.1b
unnamed: D4.2 (A), J100.5a, J100.5b
unnamed: D11.2 (A), D12.2 (A)
unnamed: D13.2 (A), D14.2 (A)
unnamed: J200.2, JP3.1 (A)
unnamed: J200.3, JP4.1 (A)
unnamed: J200.7, JP2.1 (A)
unnamed: J200.10, JP1.1 (A)
unnamed: Q9.2 (B), R76.1, R77.2
unnamed: Q10.2 (B), R78.1, R79.2
unnamed: C23.2, Q10.1 (C), Q12.2 (B), R83.1
unnamed: C22.2, Q9.1 (C), Q11.2 (B), R82.1
unnamed: R7.1, R9.2, U3.7
unnamed: R84.1, R90.1, U10.1
unnamed: R87.1, R91.1, U10.14
unnamed: R96.2, R98.1
unnamed: R97.2, R99.1
unnamed: R98.2, R100.1, U10.7
unnamed: R99.2, R101.1, U10.8
unnamed: R4.1, R7.2, U3.6 (-)
unnamed: R9.1, R10.2, R11.2, U3.9 (-)
unnamed: U3.13 (-), U3.14
unnamed: R3.2, RV1.1, U4.2 (-)
unnamed: R6.2, R8.1, U4.6 (-)
unnamed: R80.2, R84.2, U10.2 (-)
unnamed: R92.2, R94.2, R96.1, U10.6 (-)
unnamed: R93.2, R95.2, R97.1, U10.9 (-)
unnamed: R81.2, R87.2, U10.13 (-)

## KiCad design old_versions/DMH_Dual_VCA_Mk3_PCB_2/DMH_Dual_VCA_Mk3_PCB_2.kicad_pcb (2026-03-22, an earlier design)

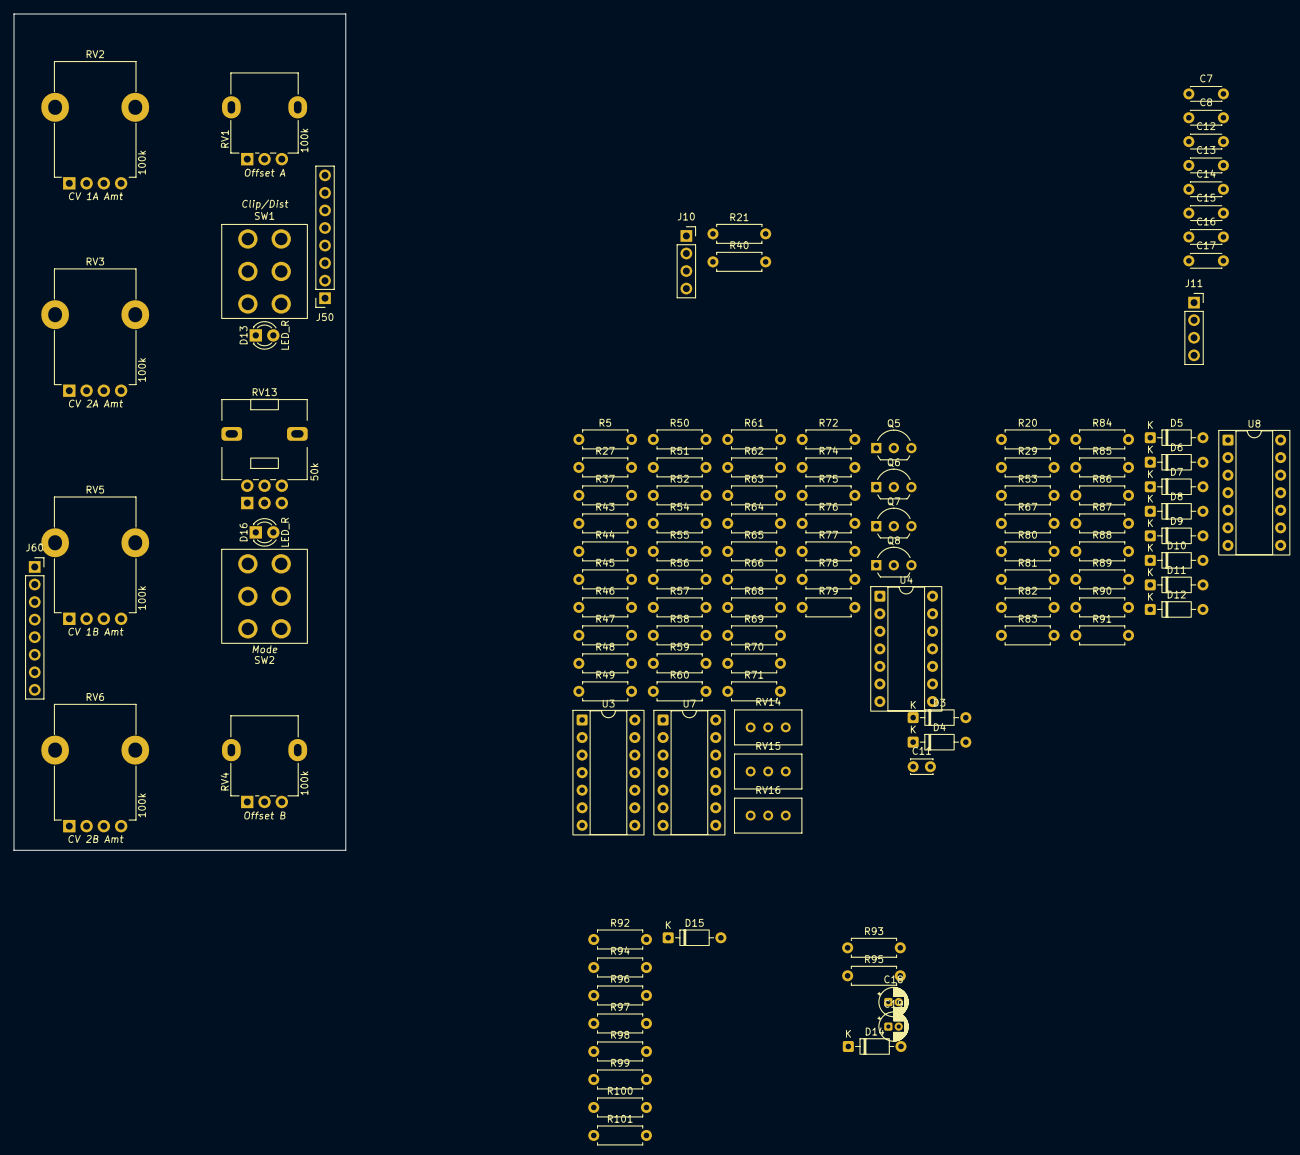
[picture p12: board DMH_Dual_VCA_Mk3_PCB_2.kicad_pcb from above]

Board: 2 copper layers, 48.0 x 121.0 mm, 114 parts (0 on the bottom side), 90 nets, no tracks yet.

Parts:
C7, C8, C12, C13, C14, C15, C16, C17: 100nF; C_Disc_D4.3mm_W1.9mm_P5.00mm
C11: 22pF; C_Disc_D3.0mm_W2.0mm_P2.50mm
C18, C19: 2.2uF; CP_Radial_D4.0mm_P1.50mm
D3, D4, D14, D15: 1N4148; D_DO-35_SOD27_P7.62mm_Horizontal
D5, D6, D7, D8: ZPD4V7; D_DO-35_SOD27_P7.62mm_Horizontal
D9, D10, D11, D12: ZPD3V0; D_DO-35_SOD27_P7.62mm_Horizontal
D13, D16: LED_R; LED_D3.0mm
J10: Conn_01x04; PinSocket_1x04_P2.54mm_Vertical
J11: Conn_01x04_PinHeader; PinSocket_1x04_P2.54mm_Vertical
J50, J60: Conn_01x08; PinSocket_1x08_P2.54mm_Vertical
Q5, Q6, Q7, Q8: BC548; TO-92L_Inline_Wide
R5, R27, R29, R37, R50, R51, R52, R53, R54, R55, R56, R64, R65, R66, R67, R69, R70, R71, R72, R74, R75, R76, R80, R81, R83, R85, R87, R94, R99: 100k; R_Axial_DIN0207_L6.3mm_D2.5mm_P7.62mm_Horizontal
R20, R84, R88, R89: 2k2; R_Axial_DIN0207_L6.3mm_D2.5mm_P7.62mm_Horizontal
R21, R40: 18k; R_Axial_DIN0207_L6.3mm_D2.5mm_P7.62mm_Horizontal
R43, R47, R57, R63: 100R; R_Axial_DIN0207_L6.3mm_D2.5mm_P7.62mm_Horizontal
R44, R46, R58, R60, R77, R78, R92, R100: 20k; R_Axial_DIN0207_L6.3mm_D2.5mm_P7.62mm_Horizontal
R45, R48, R49, R59, R61, R62, R79: 10k; R_Axial_DIN0207_L6.3mm_D2.5mm_P7.62mm_Horizontal
R68: 33k; R_Axial_DIN0207_L6.3mm_D2.5mm_P7.62mm_Horizontal
R82, R86: 220k; R_Axial_DIN0207_L6.3mm_D2.5mm_P7.62mm_Horizontal
R90, R91, R95, R96: 1k; R_Axial_DIN0207_L6.3mm_D2.5mm_P7.62mm_Horizontal
R93, R101: 3k3; R_Axial_DIN0207_L6.3mm_D2.5mm_P7.62mm_Horizontal
R97, R98: 330k; R_Axial_DIN0207_L6.3mm_D2.5mm_P7.62mm_Horizontal
RV1, RV4: 100k; Potentiometer_Alpha_RD901F-40-00D_Single_Vertical
RV2, RV3, RV5, RV6: 100k; Potentiometer_TT_P110KH1
RV13: 50k; Potentiometer_Alps_RK09L_Double_Vertical
RV14, RV15: 100k; Potentiometer_Bourns_3296W_Vertical
RV16: 50k; Potentiometer_Bourns_3296W_Vertical
SW1: SW_DPDT_OnOffOn_x2; Toggle_Switch_2_Poles_TE
SW2: SW_DPDT_3way; Toggle_Switch_2_Poles_TE
U3, U4, U7, U8: TL074; DIP-14_W7.62mm_Socket

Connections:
+5V: J10.1, R92.2, R100.2, RV13.6, SW2.1 (A)
+12V: C7.1, C12.1, C14.1, C16.1, J50.3, J60.3, R21.2, R40.2, R44.2, R46.2, R58.2, R60.2, RV14.3, RV15.3, U3.4 (V+), U4.4 (V+), U7.4 (V+), U8.4 (V+)
-5V: J10.2, R79.1, RV13.4
-12V: C8.2, C13.2, C15.2, C17.2, J50.7, J60.7, RV14.1, RV15.1, U3.11 (V-), U4.11 (V-), U7.11 (V-), U8.11 (V-)
/2nd VCA/Attenuverted CV PT: R54.1, R69.1, RV16.2, RV16.3, SW2.6 (C), U4.1
/2nd VCA/Balanced Offset: R78.1, SW2.3 (C), U7.8
/2nd VCA/CV PT Input: J10.3, R68.1, RV13.3
/2nd VCA/CV PT Offset: R5.1, R71.1, SW2.2 (B)
/2nd VCA/CV PT Pot G1: RV13.2, U4.3 (+)
/2nd VCA/CV PT Pot G2: RV13.5, U7.3 (+)
/2nd VCA/Input A: J11.1, R37.2
/2nd VCA/Input B: J11.4, R56.2
/2nd VCA/Inverted CV PT: R70.2, SW2.4 (A), U4.7
/2nd VCA/Output A: R52.1, R53.1, R96.2, U3.8
/2nd VCA/Output B: R29.1, R66.1, R95.2, U3.7
/Clipping/Output A: J11.2, R90.2
/Clipping/Output B: J11.3, R91.2
/Inputs and Outputs/CV 1 A Jack: J50.1, RV2.3
/Inputs and Outputs/CV 1 A Pot: J50.5, RV2.2
/Inputs and Outputs/CV 1 B Jack: J60.1, RV5.3
/Inputs and Outputs/CV 1 B Pot: J60.5, RV5.2
/Inputs and Outputs/CV 2 A Jack: J50.2, RV3.3
/Inputs and Outputs/CV 2 A Pot: J50.6, RV3.2
/Inputs and Outputs/CV 2 B Jack: J60.2, RV6.3
/Inputs and Outputs/CV 2 B Pot: J60.6, RV6.2
/Inputs and Outputs/Offset A Pot: J50.4, RV1.2
/Inputs and Outputs/Offset B Pot: J60.4, RV4.2
GND: C7.2, C8.1, C12.2, C13.1, C14.2, C15.1, C16.2, C17.1, C18.2, C19.2, D6.1 (K), D8.1 (K), D10.1 (K), D12.1 (K), D13.1 (K), D16.1 (K), J10.4, J50.8, J60.8, R43.1, R47.1, R51.2, R57.1, R63.1, R65.2, R76.2, R94.1, R97.1, R98.1, R99.1, RV1.1, RV2.1, RV3.1, RV4.1, RV5.1, RV6.1, RV13.1, U3.3 (+), U3.12 (+), U4.5 (+), U7.10 (+), U7.12 (+), U8.3 (+), U8.5 (+), U8.10 (+), U8.12 (+)
unnamed: C11.2, D3.2 (A), R74.2, U7.2 (-)
unnamed: C11.1, D3.1 (K), D4.2 (A), U7.1
unnamed: D4.1 (K), R76.1, U7.5 (+)
unnamed: D5.2 (A), D6.2 (A)
unnamed: D5.1 (K), SW1.3 (C)
unnamed: D7.2 (A), D8.2 (A)
unnamed: D7.1 (K), SW1.6 (C)
unnamed: D9.1 (K), R82.1, SW1.1 (A)
unnamed: D9.2 (A), D10.2 (A)
unnamed: D11.2 (A), D12.2 (A)
unnamed: D11.1 (K), R86.1, SW1.4 (A)
unnamed: D13.2 (A), R93.2
unnamed: D14.2 (A), R95.1
unnamed: C19.1, D14.1 (K), R98.2, U4.12 (+)
unnamed: D15.2 (A), R96.1
unnamed: C18.1, D15.1 (K), R97.2, U4.10 (+)
unnamed: D16.2 (A), R101.2
unnamed: Q5.2 (B), R37.1, R43.2
unnamed: Q5.1 (C), R44.1, R48.2
unnamed: Q5.3 (E), Q6.3 (E), R45.2
unnamed: Q6.2 (B), R47.2, R50.2
unnamed: Q6.1 (C), R46.1, R49.2
unnamed: Q7.2 (B), R56.1, R57.2
unnamed: Q7.1 (C), R58.1, R61.2
unnamed: Q7.3 (E), Q8.3 (E), R59.2
unnamed: Q8.2 (B), R63.2, R64.2
unnamed: Q8.1 (C), R60.1, R62.2
unnamed: R20.1, R67.1, U8.1
unnamed: R21.1, RV1.3
unnamed: R27.2, R59.1, U3.1
unnamed: R40.1, RV4.3
unnamed: R45.1, R72.2, U3.14
unnamed: R50.1, RV14.2
unnamed: R55.1, SW2.5 (B)
unnamed: R64.1, RV15.2
unnamed: R75.1, R77.2, U7.7
unnamed: R80.2, R88.1
unnamed: R83.1, R84.1, U8.14
unnamed: R87.2, R89.1
unnamed: R88.2, R90.1, U8.7
unnamed: R89.2, R91.1, U8.8
unnamed: R93.1, U4.8
unnamed: R101.1, U4.14
unnamed: R20.2, R81.1, SW1.2 (B)
unnamed: R84.2, R85.1, SW1.5 (B)
unnamed: R5.2, R27.1, R54.2, U3.2 (-)
unnamed: R62.1, R65.1, U3.5 (+)
unnamed: R61.1, R66.2, U3.6 (-)
unnamed: R49.1, R51.1, U3.10 (+)
unnamed: R48.1, R52.2, U3.9 (-)
unnamed: R55.2, R71.2, R72.1, U3.13 (-)
unnamed: R68.2, RV16.1, U4.2 (-)
unnamed: R69.2, R70.1, U4.6 (-)
unnamed: R92.1, R94.2, U4.9 (-)
unnamed: R99.2, R100.1, U4.13 (-)
unnamed: R74.1, R75.2, U7.6 (-)
unnamed: R77.1, R78.2, R79.2, U7.9 (-)
unnamed: U7.13 (-), U7.14
unnamed: R53.2, R67.2, U8.2 (-)
unnamed: R80.1, R81.2, R82.2, U8.6 (-)
unnamed: R85.2, R86.2, R87.1, U8.9 (-)
unnamed: R29.2, R83.2, U8.13 (-)

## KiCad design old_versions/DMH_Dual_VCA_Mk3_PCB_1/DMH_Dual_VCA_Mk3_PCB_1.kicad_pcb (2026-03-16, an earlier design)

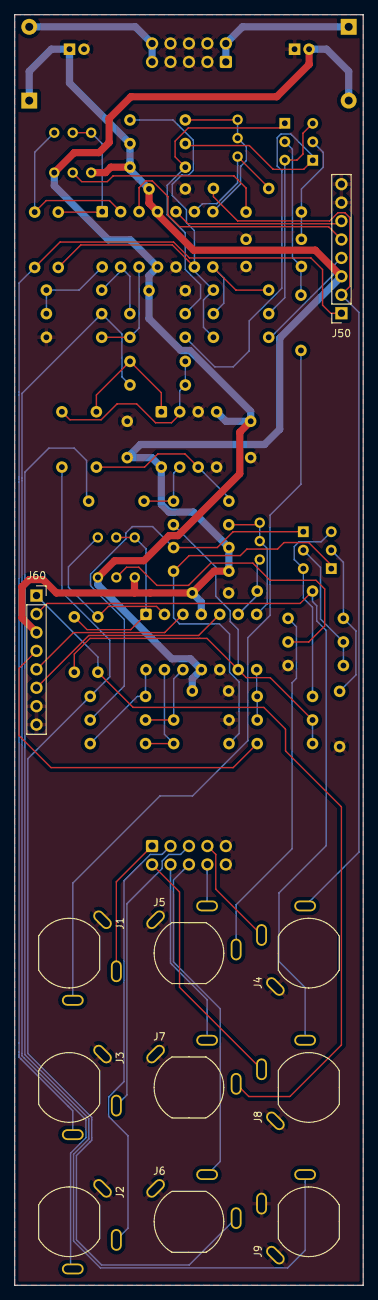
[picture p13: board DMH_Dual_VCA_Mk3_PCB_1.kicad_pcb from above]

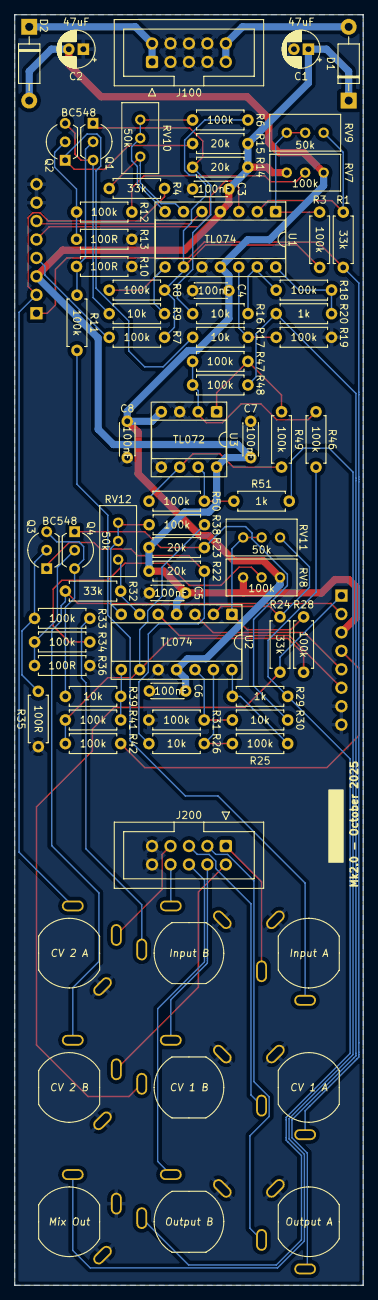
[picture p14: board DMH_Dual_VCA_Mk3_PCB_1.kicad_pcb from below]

Board: 2 copper layers, 48.0 x 175.0 mm, 78 parts (67 on the bottom side), 62 nets.

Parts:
C1, C2: 47uF; CP_Radial_D5.0mm_P2.00mm
C3, C4, C5, C6, C7, C8: 100nF; C_Disc_D4.3mm_W1.9mm_P5.00mm
D1: SB140+; D_DO-41_SOD81_P10.16mm_Horizontal
D2: SB140-; D_DO-41_SOD81_P10.16mm_Horizontal
J1, J2, J3, J4, J5, J6, J7, J8, J9: TS_Jack_6.35mm_Sw; CUI_MJ-63052A
J50, J60: Conn_01x08; PinSocket_1x08_P2.54mm_Vertical
J100: IDC_02x05; IDC-Header_2x05_P2.54mm_Vertical_Eurorack
J200: IDC_02x05; IDC-Header_2x05_P2.54mm_Vertical_BackBone
Q1, Q2, Q3, Q4: BC548; TO-92L_Inline_Wide
R1, R4, R24, R32: 33k; R_Axial_DIN0207_L6.3mm_D2.5mm_P7.62mm_Horizontal
R3, R6, R7, R8, R11, R12, R18, R19, R25, R28, R31, R33, R34, R38, R41, R42, R46, R47, R48, R49, R50: 100k; R_Axial_DIN0207_L6.3mm_D2.5mm_P7.62mm_Horizontal
R9, R16, R17, R26, R30, R39: 10k; R_Axial_DIN0207_L6.3mm_D2.5mm_P7.62mm_Horizontal
R10, R13, R35, R36: 100R; R_Axial_DIN0207_L6.3mm_D2.5mm_P7.62mm_Horizontal
R14, R15, R22, R23: 20k; R_Axial_DIN0207_L6.3mm_D2.5mm_P7.62mm_Horizontal
R20, R29, R51: 1k; R_Axial_DIN0207_L6.3mm_D2.5mm_P7.62mm_Horizontal
RV7, RV8: 100k; Potentiometer_Bourns_3296W_Vertical
RV9, RV10, RV11, RV12: 50k; Potentiometer_Bourns_3296W_Vertical
U1, U2: TL074; DIP-14_W7.62mm_Socket
U3: TL072; DIP-8_W7.62mm_Socket

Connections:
+12V: C1.1, C3.1, C5.1, C7.1, D1.1 (K), J50.3, J60.3, R14.2, R15.2, R22.2, R23.2, RV7.3, RV8.3, U1.4 (V+), U2.4 (V+), U3.8 (V+)
-12V: C2.2, C4.2, C6.2, C8.2, D2.2 (A), RV7.1, RV8.1, U1.11 (V-), U2.11 (V-), U3.4 (V-)
/Core Circuit A/CV 1 A Input: J3.T, J50.1, R1.1
/Core Circuit A/CV 1 A Pot: J50.5, U1.3 (+)
/Core Circuit A/CV 2 A Input: J4.T, J50.2, R4.1
/Core Circuit A/CV 2 A Pot: J50.6, U1.5 (+)
/Core Circuit A/Input A: J1.T, R11.2
/Core Circuit A/Offset A Pot: J50.4, R7.1
/Core Circuit A/Output A: J2.T, R20.1, R48.1
/Core Circuit B/CV 1 B Input: J7.T, J60.1, R24.1
/Core Circuit B/CV 1 B Pot: J60.5, U2.3 (+)
/Core Circuit B/CV 2 B Input: J8.T, J60.2, R32.1
/Core Circuit B/CV 2 B Pot: J60.6, U2.5 (+)
/Core Circuit B/Input B: J5.T, R33.2
/Core Circuit B/Offset B Pot: J60.4, R42.1
/Core Circuit B/Output B: J6.T, R29.1, R46.1
/Inputs and Outputs/Mix Out Jack: J9.T, R51.2
GND: C1.2, C2.1, C3.2, C4.1, C5.2, C6.1, C7.2, C8.1, J1.S, J2.S, J3.S, J4.S, J5.S, J6.S, J7.S, J8.S, J9.S, J9.TN, J50.7, J50.8, J60.7, J60.8, J100.2a, J100.2b, J100.3a, J100.3b, J100.4a, J100.4b, J200.5, J200.10, R10.1, R13.1, R19.2, R31.2, R35.1, R36.1, U1.10 (+), U2.10 (+), U3.3 (+), U3.5 (+)
unnamed: D1.2 (A), J100.5a, J100.5b
unnamed: D2.1 (K), J100.1a, J100.1b
unnamed: J1.TN, J200.1
unnamed: J2.TN, J200.2
unnamed: J3.TN, J200.3
unnamed: J4.TN, J200.4
unnamed: J8.TN, J200.6
unnamed: J7.TN, J200.7
unnamed: J6.TN, J200.8
unnamed: J5.TN, J200.9
unnamed: Q1.2 (B), R10.2, R11.1
unnamed: Q1.1 (C), R14.1, R16.2
unnamed: Q1.3 (E), Q2.3 (E), R9.2
unnamed: Q2.2 (B), R12.2, R13.2
unnamed: Q2.1 (C), R15.1, R17.2
unnamed: Q3.2 (B), R33.1, R35.2
unnamed: Q3.1 (C), R22.1, R26.2
unnamed: Q3.3 (E), Q4.3 (E), R39.2
unnamed: Q4.2 (B), R34.2, R36.2
unnamed: Q4.1 (C), R23.1, R30.2
unnamed: R3.1, RV9.2, RV9.3, U1.1
unnamed: R6.1, RV10.2, RV10.3, U1.7
unnamed: R8.2, R9.1, U1.8
unnamed: R12.1, RV7.2
unnamed: R18.1, R20.2, U1.14
unnamed: R25.1, R29.2, U2.14
unnamed: R28.1, RV11.2, RV11.3, U2.1
unnamed: R34.1, RV8.2
unnamed: R38.1, RV12.2, RV12.3, U2.7
unnamed: R39.1, R41.2, U2.8
unnamed: R47.2, R49.1, U3.1
unnamed: R50.2, R51.1, U3.7
unnamed: R1.2, RV9.1, U1.2 (-)
unnamed: R4.2, RV10.1, U1.6 (-)
unnamed: R3.2, R6.2, R7.2, R8.1, U1.9 (-)
unnamed: R17.1, R19.1, U1.12 (+)
unnamed: R16.1, R18.2, U1.13 (-)
unnamed: R24.2, RV11.1, U2.2 (-)
unnamed: R32.2, RV12.1, U2.6 (-)
unnamed: R28.2, R38.2, R41.1, R42.2, U2.9 (-)
unnamed: R30.1, R31.1, U2.12 (+)
unnamed: R25.2, R26.1, U2.13 (-)
unnamed: R46.2, R47.1, R48.2, U3.2 (-)
unnamed: R49.2, R50.1, U3.6 (-)

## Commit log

2026-03-16 Designed mk3 panel
    Added Pan/Tremolo switch and amount knob
    Added Clip switch
    [DMH_Dual_VCA_Mk3_PANEL.kicad_pcb, DMH_Dual_VCA_Mk3_PANEL.kicad_sch]
2026-03-16 Started PCB 2 project
    [Core_Circuit.kicad_sch, Core_Circuit_A.kicad_sch, Core_Circuit_B.kicad_sch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]
2026-03-16 PCB 1 circuit design ongoing
    [2nc_VCA.kicad_sch, Core_Circuit.kicad_sch, Core_Circuit_A.kicad_sch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]
2026-03-17 Mode switching design in progress
    [2nc_VCA.kicad_sch, DMH_Dual_VCA_Mk3_PANEL.kicad_pcb, DMH_Dual_VCA_Mk3_PANEL.kicad_sch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]
2026-03-19 2nd VCA design done
    Clipping design in progress
    [2nc_VCA.kicad_sch, Clipping.kicad_sch, Core_Circuit_A.kicad_sch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]
2026-03-20 Designed clip and dist circuit
    [2nc_VCA.kicad_sch, Clipping.kicad_sch, Core_Circuit_A.kicad_sch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]
2026-03-20 Synced PCB 1 and 2 schematics
    [2nc_VCA.kicad_sch, Clipping.kicad_sch, Core_Circuit_A.kicad_sch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]
2026-03-20 Added clipping LED to schematic
    Still need to add to Panel
    [2nc_VCA.kicad_sch, Clipping.kicad_sch, DMH_Dual_VCA_Mk3_PCB_1.kicad_sch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]
2026-03-22 Improved clipping indication
    [2nc_VCA.kicad_sch, Clipping.kicad_sch, DMH_Dual_VCA_Mk3_PANEL.kicad_pcb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]
2026-03-22 Positioned controls on PCB 2
    [Clipping.kicad_sch, DMH_Dual_VCA_Mk3_PCB_2.kicad_pcb, Inputs_and_Outputs.kicad_sch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]
2026-03-23 Synced PCB1 to PCB2
    [Clipping.kicad_sch, Inputs_and_Outputs.kicad_sch]
2026-03-23 Improved cipping indication LED drive
    [Clipping.kicad_sch, Core_Circuit_B.kicad_sch]
2026-04-12 Improved clipping indicator
    [2nc_VCA.kicad_sch, Clipping.kicad_sch, Power.kicad_sch]
2026-04-19 Created proper Controls PCB project
    [2nc_VCA.kicad_sch, Clipping.kicad_sch, Core_Circuit.kicad_sch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]
2026-05-19 KiCad 10 and updated SynthStuff
    [2nc_VCA.kicad_sch, Clipping.kicad_sch, Core_Circuit_A.kicad_sch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]
2026-05-22 Restarting schematic drawing
    [DMH_Dual_VCA_Mk3_PCB_Controls.kicad_sch, Power.kicad_sch, VCA_DiffAmp_Subcircuit.kicad_sch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]
2026-05-23 Experimenting with VCA design blocks
    [2nc_VCA.kicad_sch, Clipping.kicad_sch, Core_Circuit.kicad_sch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]
2026-05-25 Redesigned schematic layout
    [Clipping.kicad_sch, Controls.kicad_sch, DMH_Dual_VCA_Mk3_PCB_Controls.kicad_sch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]
2026-05-25 schematic labeling in progress
    [DMH_Dual_VCA_Mk3_PCB_Controls.kicad_sch]
2026-05-25 Schematic redesign done
    [Clipping.kicad_sch, Controls.kicad_sch, DMH_Dual_VCA_Mk3_PCB_Main.kicad_pcb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]
2026-05-25 Controls PCB comp placement started
    [Controls.kicad_sch, DMH_Dual_VCA_Mk3_PCB_Controls.kicad_pcb, DMH_Dual_VCA_Mk3_PCB_Controls.kicad_sch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]
2026-05-26 Moved clipping circuit back to main PCB
    [Clipping.kicad_sch, Controls.kicad_sch, DMH_Dual_VCA_Mk3_PCB_Controls.kicad_pcb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]
2026-05-27 Controls PCB comp placement in progress
    [Clipping.kicad_sch, Controls.kicad_sch, DMH_Dual_VCA_Mk3_PCB_Controls.kicad_pcb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]
2026-05-28 Controls PCB comp placement done
    [DMH_Dual_VCA_Mk3_PCB_Controls.kicad_pcb, DMH_Dual_VCA_Mk3_PCB_Controls.kicad_sch]
2026-05-28 Controls PCB routing done
    [DMH_Dual_VCA_Mk3_PCB_Controls.kicad_pcb, DMH_Dual_VCA_Mk3_PCB_Controls.kicad_sch]
2026-05-30 Started Main PCB comp placement
    [Clipping.kicad_sch, Controls.kicad_sch, DMH_Dual_VCA_Mk3_PCB_Controls.kicad_pcb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]
2026-05-30 Comp placement in progress
    [DMH_Dual_VCA_Mk3_PCB_Controls.kicad_sch, DMH_Dual_VCA_Mk3_PCB_Main.kicad_pcb, DMH_Dual_VCA_Mk3_PCB_Main.kicad_sch]
2026-05-30 Main comp placement in progress
    [Clipping.kicad_sch, DMH_Dual_VCA_Mk3_PCB_Main.kicad_pcb, DMH_Dual_VCA_Mk3_PCB_Main.kicad_sch]
2026-06-01 Main comp placement done
    [DMH_Dual_VCA_Mk3_PCB_Main.kicad_pcb, DMH_Dual_VCA_Mk3_PCB_Main.kicad_sch]
2026-06-01 Started Main PCB routing
    [DMH_Dual_VCA_Mk3_PCB_Main.kicad_pcb]
2026-06-14 Added jumpers to normalize CV inputs B to A
    [DMH_Dual_VCA_Mk3_PCB_Controls.kicad_pcb, DMH_Dual_VCA_Mk3_PCB_Controls.kicad_sch, DMH_Dual_VCA_Mk3_PCB_Main.kicad_pcb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]
2026-06-14 Fixed -5V supply circuit mistake
    [DMH_Dual_VCA_Mk3_PCB_Controls.kicad_sch, DMH_Dual_VCA_Mk3_PCB_Main.kicad_pcb, DMH_Dual_VCA_Mk3_PCB_Main.kicad_sch]
2026-06-16 Added jumper to normalize Input B to A
    [DMH_Dual_VCA_Mk3_PCB_Controls.kicad_sch, DMH_Dual_VCA_Mk3_PCB_Main.kicad_pcb, DMH_Dual_VCA_Mk3_PCB_Main.kicad_sch]
2026-06-19 Main PCB routing in progress
    [DMH_Dual_VCA_Mk3_PCB_Controls.kicad_sch, DMH_Dual_VCA_Mk3_PCB_Main.kicad_pcb, DMH_Dual_VCA_Mk3_PCB_Main.kicad_sch]
2026-06-19 Main PCB routing done
    [DMH_Dual_VCA_Mk3_PCB_Controls.kicad_sch, DMH_Dual_VCA_Mk3_PCB_Main.kicad_pcb, DMH_Dual_VCA_Mk3_PCB_Main.kicad_sch]
2026-06-20 Generated Gerbers
    [DMH_Dual_VCA_Mk3_PANEL-B_Cu.gbl, DMH_Dual_VCA_Mk3_PANEL-B_Mask.gbs, DMH_Dual_VCA_Mk3_PANEL-B_Paste.gbp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]
2026-06-20 Moved old versions to sub folder
    [2nc_VCA.kicad_sch, Clipping.kicad_sch, Core_Circuit.kicad_sch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]
2026-06-21 Corrected -5V symbol
    [Controls.kicad_sch, DMH_Dual_VCA_Mk3_PCB_Controls.kicad_sch, DMH_Dual_VCA_Mk3_PCB_Main.kicad_pcb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]
2026-07-12 Changed pan pot panel hole to match Alps RK09L pot
    [DMH_Dual_VCA_Mk3_PANEL-B_Cu.gbl, DMH_Dual_VCA_Mk3_PANEL-B_Mask.gbs, DMH_Dual_VCA_Mk3_PANEL-B_Paste.gbp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]
2026-08-07 Generated schematic and BoM
    [Clipping.kicad_sch, Controls.kicad_sch, DMH_Dual_VCA_Mk3_PCB_Main.kicad_sch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]
2026-08-07 Fixed Alps RK09L pot 3D model
    [Controls.kicad_sch, DMH_Dual_VCA_Mk3_PCB_Controls.kicad_pcb]
